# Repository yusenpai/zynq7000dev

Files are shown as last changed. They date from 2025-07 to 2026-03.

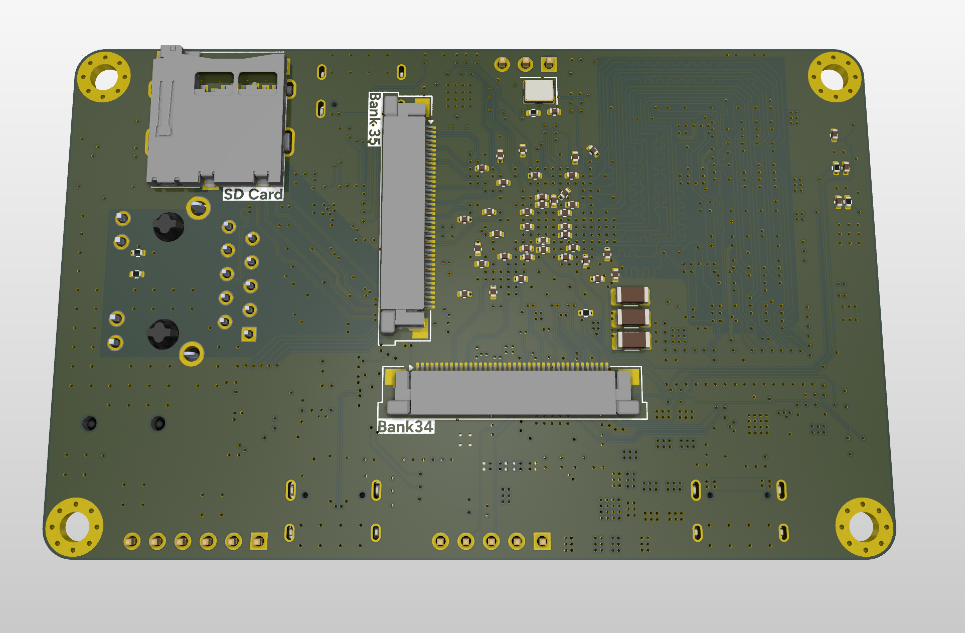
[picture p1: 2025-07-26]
demo/pcb/3d_bot.png

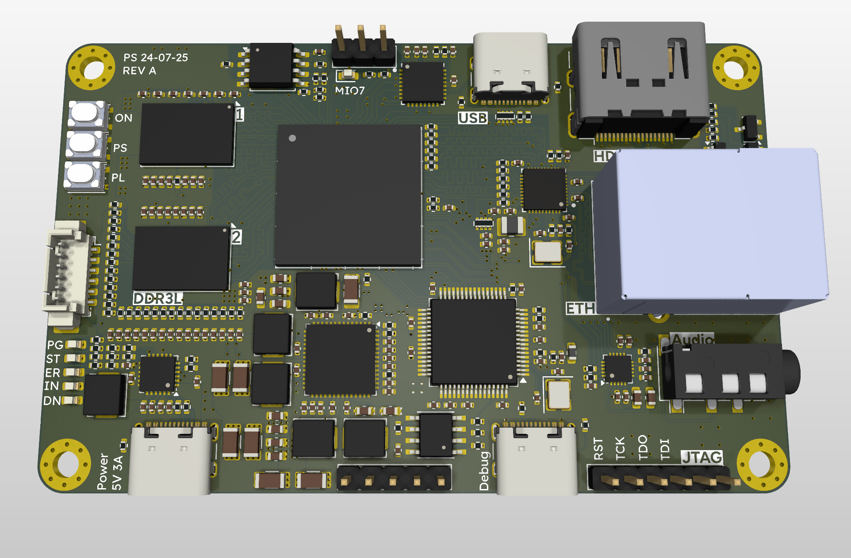
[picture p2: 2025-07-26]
demo/pcb/3d_top.png

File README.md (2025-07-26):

# Zynq 7000 SoC Dev Board

Đây là một board PCB 6 lớp thiết kế quanh con chip XC7Z010-1CLG400C, thuộc họ SoC Zynq 7000 của AMD. Con chip có một nửa là (2) lõi CPU (ARM Cortex-A9) + một đống ngoại vi (UART, I2C, SPI, USB,...); nửa còn lại là FPGA. Rất phù hợp cho những ứng dụng kết hợp Hardware + Software.

Thường thì những board FPGA (đặc biệt là thể loại SoC thế này) rất mắc tiền. Xem [https://www.amd.com/en/products/adaptive-socs-and-fpgas/evaluation-boards/ek-z7-zc702-g.html]. Trong khi đó, mạch in khá là rẻ, chip thì mình cũng kiếm được trên Aliexpress (với đi freesample), nên mình quyết định làm một board thế này.

Schematic, PCB vẫn đang trong quá trình phát triển và có thể sai sót. Mình sẽ cập nhật thêm nếu mạch chạy được 😂.

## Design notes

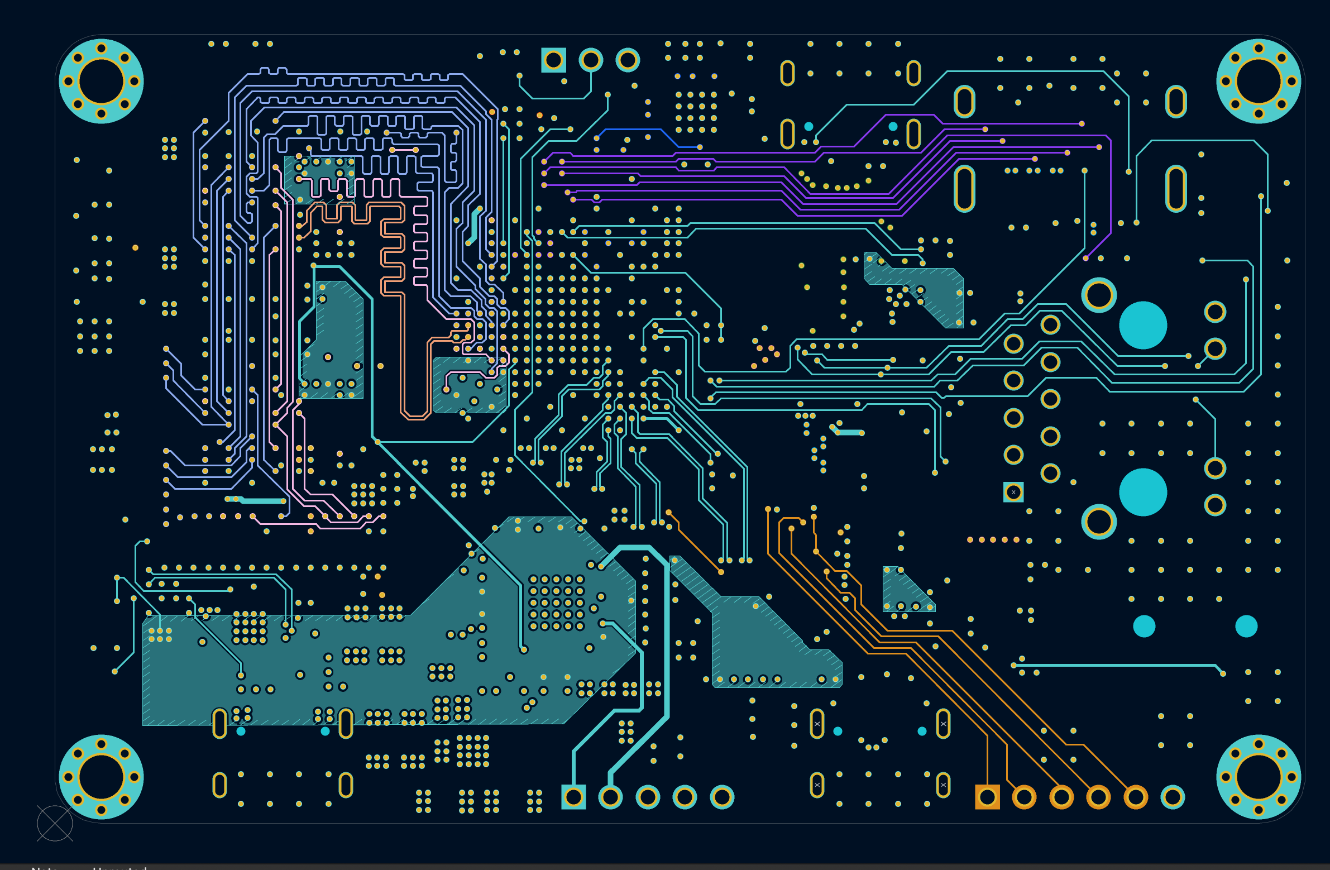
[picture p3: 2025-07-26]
demo/pcb/l3.png

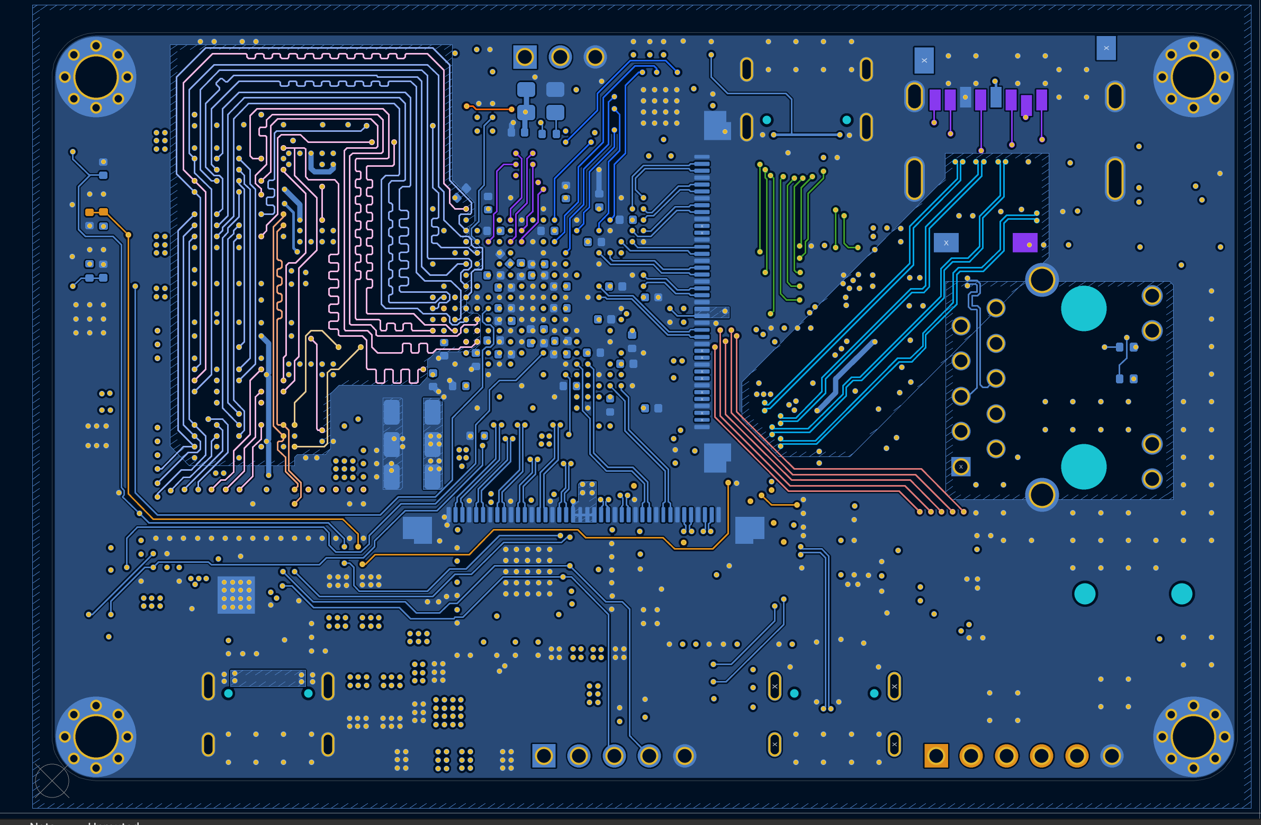
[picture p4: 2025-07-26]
demo/pcb/bot.png

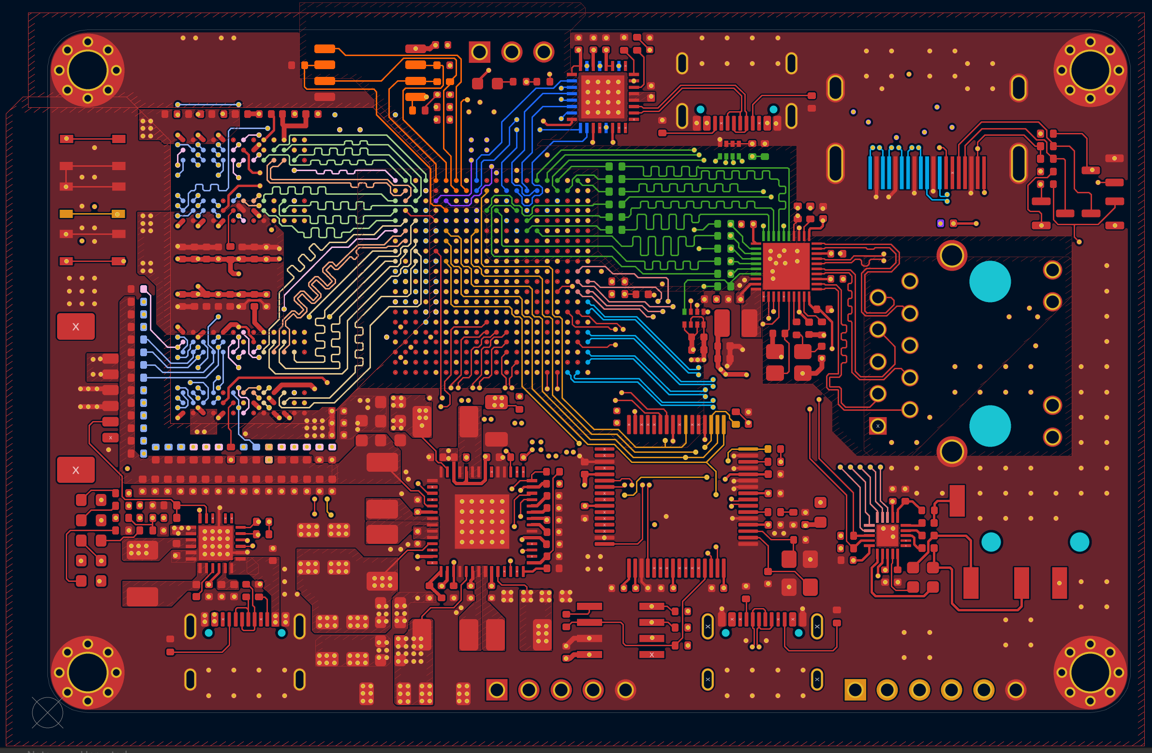
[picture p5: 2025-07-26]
demo/pcb/top.png

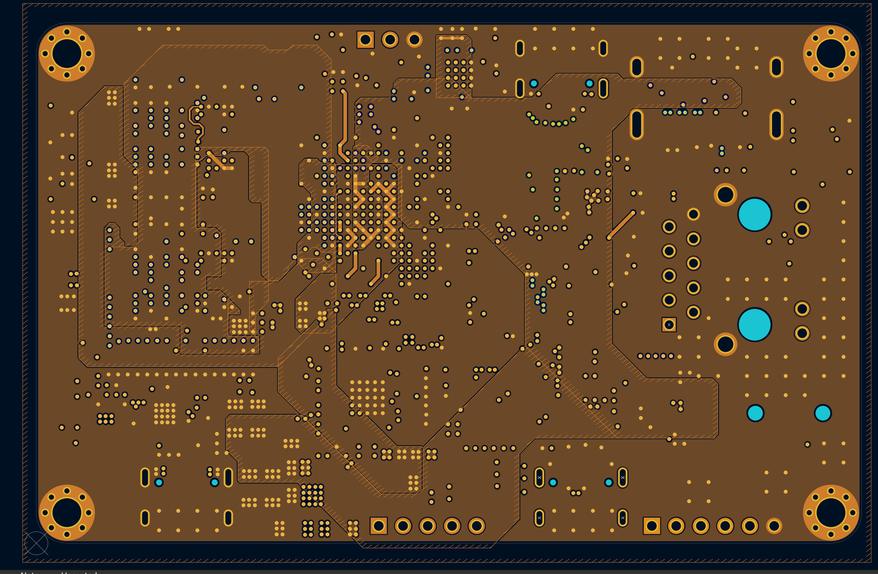
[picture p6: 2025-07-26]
demo/pcb/l2.png

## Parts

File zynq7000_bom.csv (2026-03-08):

Reference | Value | Footprint | Qty | DNP
C1,C2,C3,C4,C5,C6,C7,C8,C10,C11,C12,C13,C14,C15,C16,C17,C18,C19,C20,C21,C22,C23,C24,C25,C26,C81,C94,C95,C96,C99,C100,C103,C106,C109,C112,C115,C119,C120,C121,C122,C124,C126,C127,C128,C129,C133,C134,C135,C136,C143,C172 | 470n | Capacitor_SMD:C_0402_1005Metric | 51
C27,C28,C47 | 10n | Capacitor_SMD:C_0402_1005Metric | 3
C29,C30,C87,C89,C144,C145,C149 | 10u | Capacitor_SMD:C_0402_1005Metric | 7
C31,C32,C59,C60,C61,C62,C63,C64,C65,C88,C90,C91,C93,C98,C102,C105,C108,C111,C114,C117,C118,C125,C131,C132,C157,C168 | 4u7 | Capacitor_SMD:C_0402_1005Metric | 26
C33,C34,C35,C36,C37,C38,C39,C40,C41,C42,C43,C44,C45,C46,C48,C49,C50,C51,C54,C58,C72,C75,C80,C139,C140,C141,C142,C146,C147,C148,C150,C153,C154,C155,C156,C158,C159,C160,C161,C162,C163,C164,C165,C166,C167,C169 | 100n | Capacitor_SMD:C_0402_1005Metric | 46
C52,C53,C55,C76,C79,C82,C84,C85,C152,C175,L1,L2,L3,L4,L5,L6 | 1u | Capacitor_SMD:C_0402_1005Metric,Inductor_SMD:L_Chilisin_BMRA00040420 | 16
C56,C57,C66,C67,C68,C69,C70,C71,C73,C74,C77,C78 | 22u | Capacitor_SMD:C_0603_1608Metric | 12
C83 | 220n | Capacitor_SMD:C_0402_1005Metric | 1
C86 | 47n | Capacitor_SMD:C_0402_1005Metric | 1
C92,C97,C107,C110,C113 | 100u | Capacitor_SMD:C_1206_3216Metric | 5
C101,C104,C116,C123,C130 | 47u | Capacitor_SMD:C_1206_3216Metric | 5
C137,C138,C170,C171 | 10p | Capacitor_SMD:C_0402_1005Metric | 4
C151,C174,L7 | 2u2 | Capacitor_SMD:C_0402_1005Metric,Inductor_SMD:L_1008_2520Metric | 3
D1,D4 | RED | LED_SMD:LED_0603_1608Metric | 2
D2 | GREEN | LED_SMD:LED_0603_1608Metric | 1
D3 | BLUE | LED_SMD:LED_0603_1608Metric | 1
D5 | STAT | LED_SMD:LED_0603_1608Metric | 1
D6 | PG | LED_SMD:LED_0603_1608Metric | 1
FB1 | 600R | Inductor_SMD:L_0603_1608Metric | 1
IC1 | MMPF0100NPAEP | Package_DFN_QFN:QFN-56-1EP_8x8mm_P0.5mm_EP4.3x4.3mm | 1
J1,J2 | FPC 40 pins P0.5mm | Connector_FFC-FPC:Amphenol_F32Q-1A7x1-11040_1x40-1MP_P0.5mm_Horizontal | 2
J3,J5,J13 | Header 2.54mm | Connector_PinHeader_2.54mm:PinHeader_1x03_P2.54mm_Vertical,Connector_PinHeader_2.54mm:PinHeader_1x05_P2.54mm_Vertical,Connector_PinHeader_2.54mm:PinHeader_1x06_P2.54mm_Vertical | 3
J4 | AudioJack4 | Connector_Audio:Jack_3.5mm_PJ320D_Horizontal | 1
J6,J9,J11 | USB_C_Receptacle_USB2.0_16P | Connector_USB:USB_C_Receptacle_GCT_USB4105-xx-A_16P_TopMnt_Horizontal | 3
J7 | MX_1.25mm | Connector_Molex:Molex_PicoBlade_53398-0671_1x06-1MP_P1.25mm_Vertical | 1
J8 | HR911130A | Custom:HANRUN_HR911130A | 1
J10 | Micro_SD_Card_Det1 | Custom:5008730806 | 1
J12 | HDMI_A_1.4 | Connector_Video:HDMI_A_Molex_208658-1001_Horizontal | 1
Q1,Q2,Q3 | 2N7002 | Package_TO_SOT_SMD:SOT-23 | 3
R1,R39,R41,R52,R68,R76,R77,R79,R81,R82,R91 | 1k | Resistor_SMD:R_0402_1005Metric | 11
R2,R5,R19 | 120R | Resistor_SMD:R_0402_1005Metric | 3
R3,R4 | 240R | Resistor_SMD:R_0402_1005Metric | 2
R6,R7,R8,R35,R38,R40,R43,R50,R51,R54,R55,R56,R57,R75,R96,R97,R98,R99,R100 | 4k7 | Resistor_SMD:R_0402_1005Metric | 19
R9,R10,R11,R12,R13,R14,R15,R16,R17,R18,R20,R21,R22,R23,R24,R25,R26,R27,R28,R29,R30,R31,R32,R33 | 60R4 | Resistor_SMD:R_0402_1005Metric | 24
R34,R36,R37,R86,R90,R92,R93,R94 | 10k | Resistor_SMD:R_0402_1005Metric | 8
R42 | 330R | Resistor_SMD:R_0402_1005Metric | 1
R44,R45,R46,R47,R48,R49,R69,R70,R71,R72,R73,R74,R80,R108 | 22R | Resistor_SMD:R_0402_1005Metric | 14
R53,R64,R65 | 2k2 | Resistor_SMD:R_0402_1005Metric | 3
R58 | 100k | Resistor_SMD:R_0402_1005Metric | 1
R59 | DNP | Resistor_SMD:R_0402_1005Metric | 1
R60 | DNP | Resistor_SMD:R_0402_1005Metric | 1 | DNP
R61,R62,R66,R83,R84,R87,R88 | 5k1 | Resistor_SMD:R_0402_1005Metric | 7
R63 | 0R | Resistor_SMD:R_0402_1005Metric | 1 | DNP
R67 | 30k | Resistor_SMD:R_0402_1005Metric | 1
R78 | 2k49 | Resistor_SMD:R_0402_1005Metric | 1
R85 | 6k8 | Resistor_SMD:R_0402_1005Metric | 1
R89,R95 | 2k | Resistor_SMD:R_0402_1005Metric | 2
R101,R102,R103,R104,R105,R106,R107 | 20k | Resistor_SMD:R_0402_1005Metric | 7
R109 | 1k2 | Resistor_SMD:R_0402_1005Metric | 1
RN1,RN2 | 3k | Resistor_SMD:R_Array_Concave_4x0402 | 2
SW1,SW2,SW3 | SW_Push | Button_Switch_SMD:SW_Push_1P1T_NO_Vertical_Wuerth_434133025816 | 3
U1 | XC7Z010-1CLG400C | Custom:CLG400_XIL-L | 1
U2,U3 | H5TC2G83EFR-xxA | Package_BGA:FBGA-78_7.5x11mm_Layout2x3x13_P0.8mm | 2
U4 | SGTL5000XNLA3 | Package_DFN_QFN:QFN-20-1EP_3x3mm_P0.4mm_EP1.65x1.65mm | 1
U5 | BQ25601 | Package_DFN_QFN:Texas_RTW_WQFN-24-1EP_4x4mm_P0.5mm_EP2.7x2.7mm_ThermalVias | 1
U6 | RTL8211F-CG | Custom:RTL8211F-CG_RTK | 1
U7 | USB3320C-EZK-TR | Custom:QFN32_5X5MC_MCH | 1
U8 | W25Q128JVS | Package_SO:SOIC-8_5.3x5.3mm_P1.27mm | 1
U9 | FT4232H | Package_QFP:LQFP-64_10x10mm_P0.5mm | 1
U10 | AT93C46-10SU-2.7-T | Custom:SOIC8_4P9X3P9MC_MCH | 1
X1 | ASE-40MHz | Oscillator:Oscillator_SMD_Abracon_ASE-4Pin_3.2x2.5mm | 1
Y1 | 25MHz | Crystal:Crystal_SMD_3225-4Pin_3.2x2.5mm | 1
Y2 | 12MHz | Crystal:Crystal_SMD_3225-4Pin_3.2x2.5mm | 1

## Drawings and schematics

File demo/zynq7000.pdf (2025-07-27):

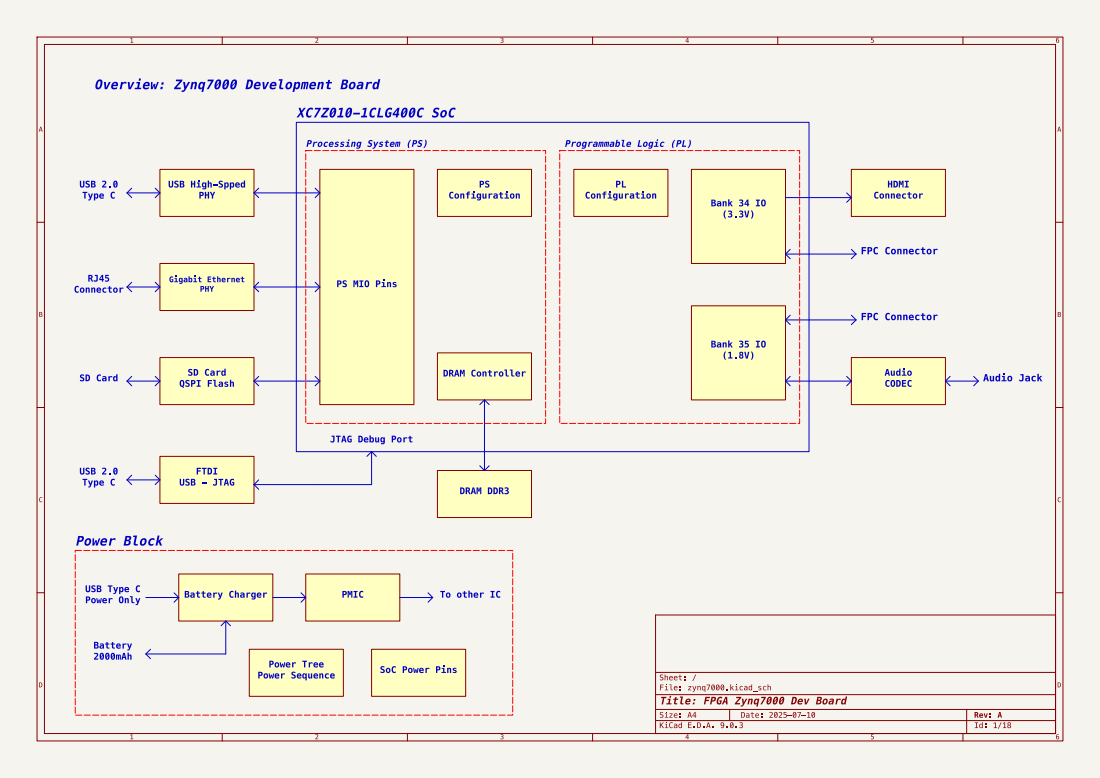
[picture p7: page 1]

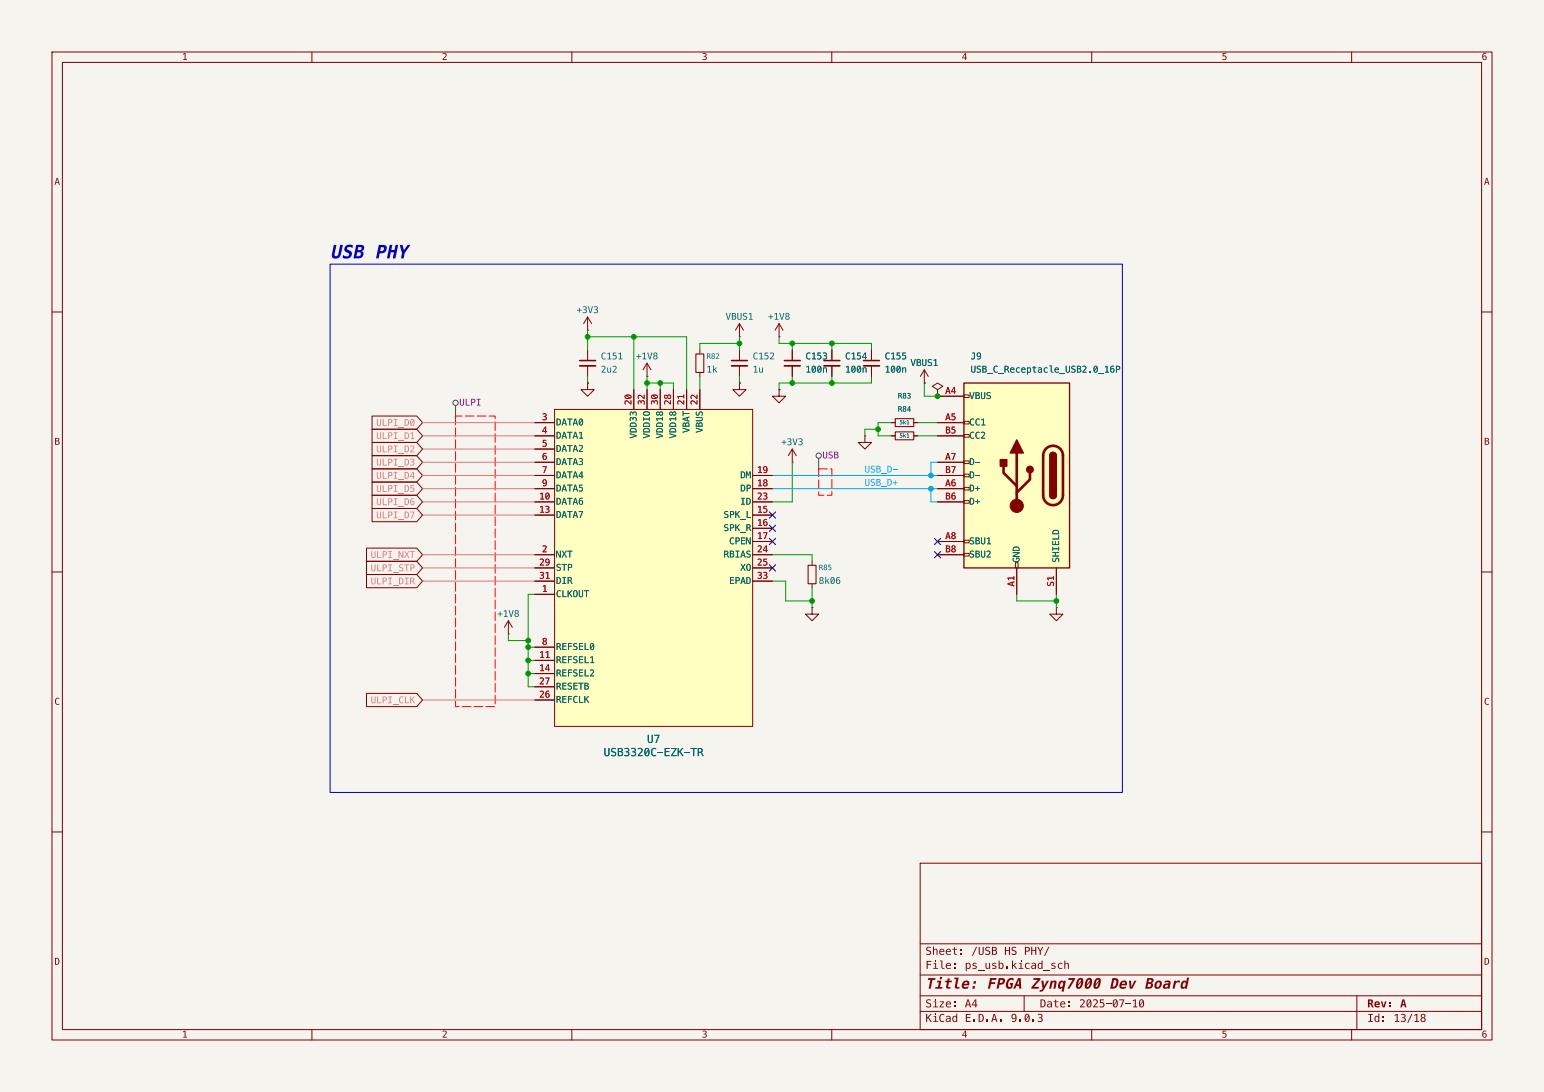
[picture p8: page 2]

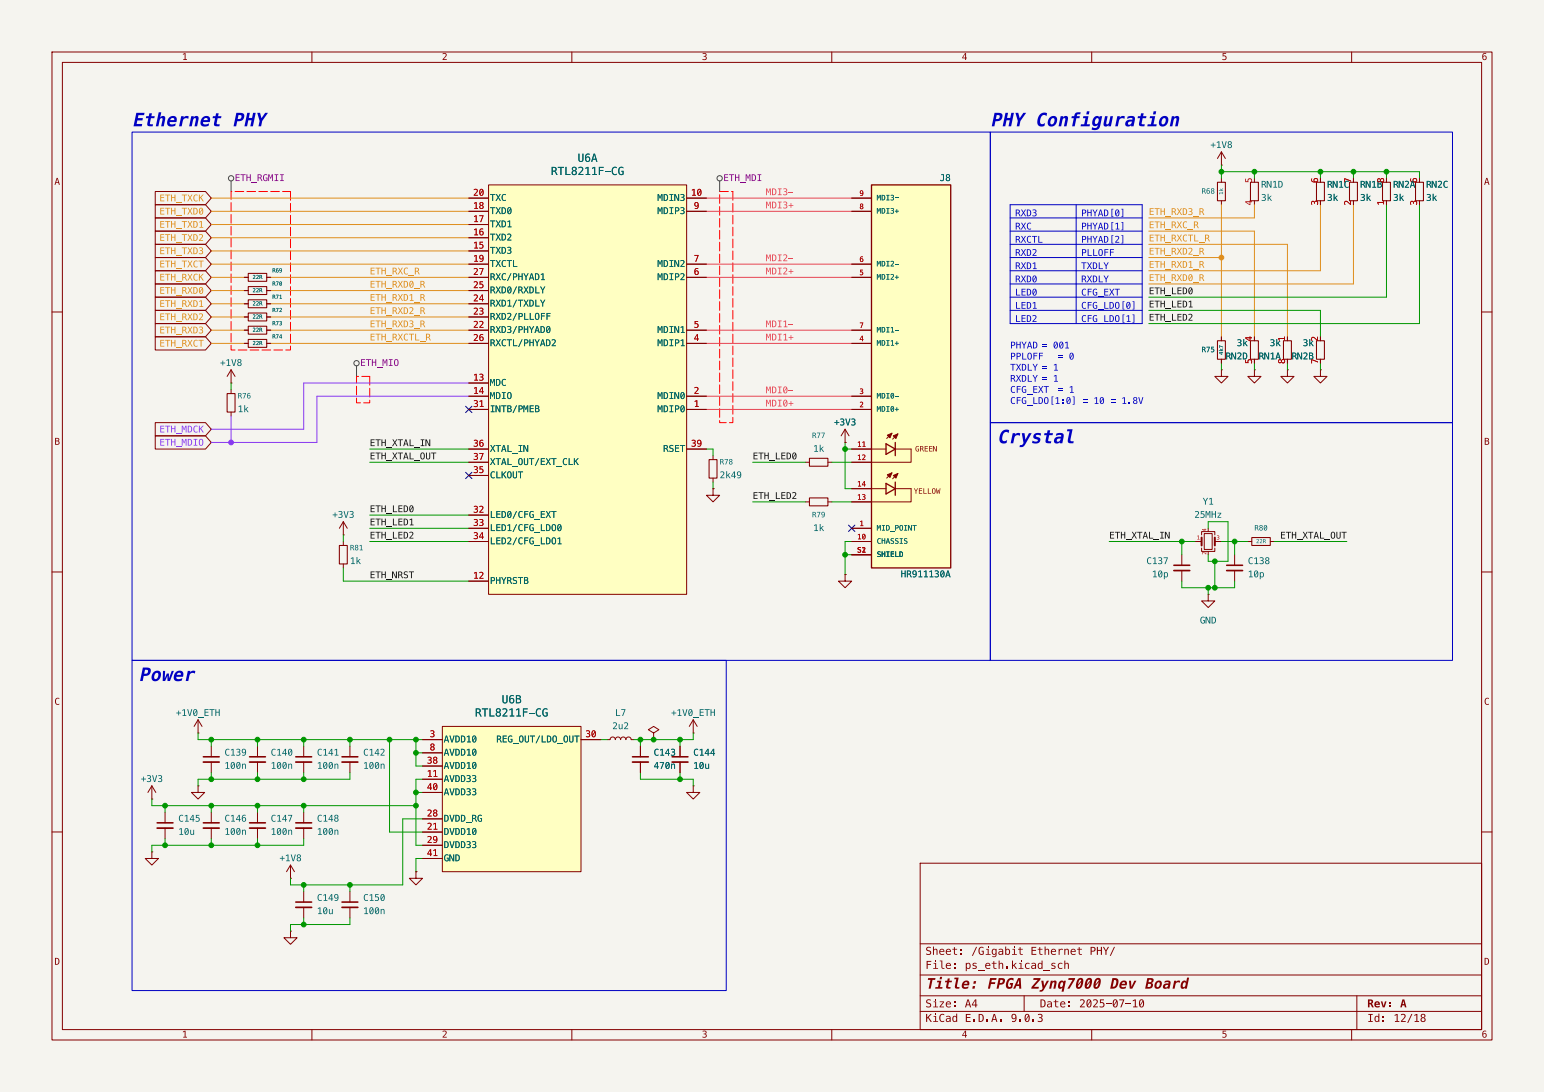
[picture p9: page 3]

22R | ETH_RXCTL_R | 5 MDIP1

2 MDIP0

Crystal

Power

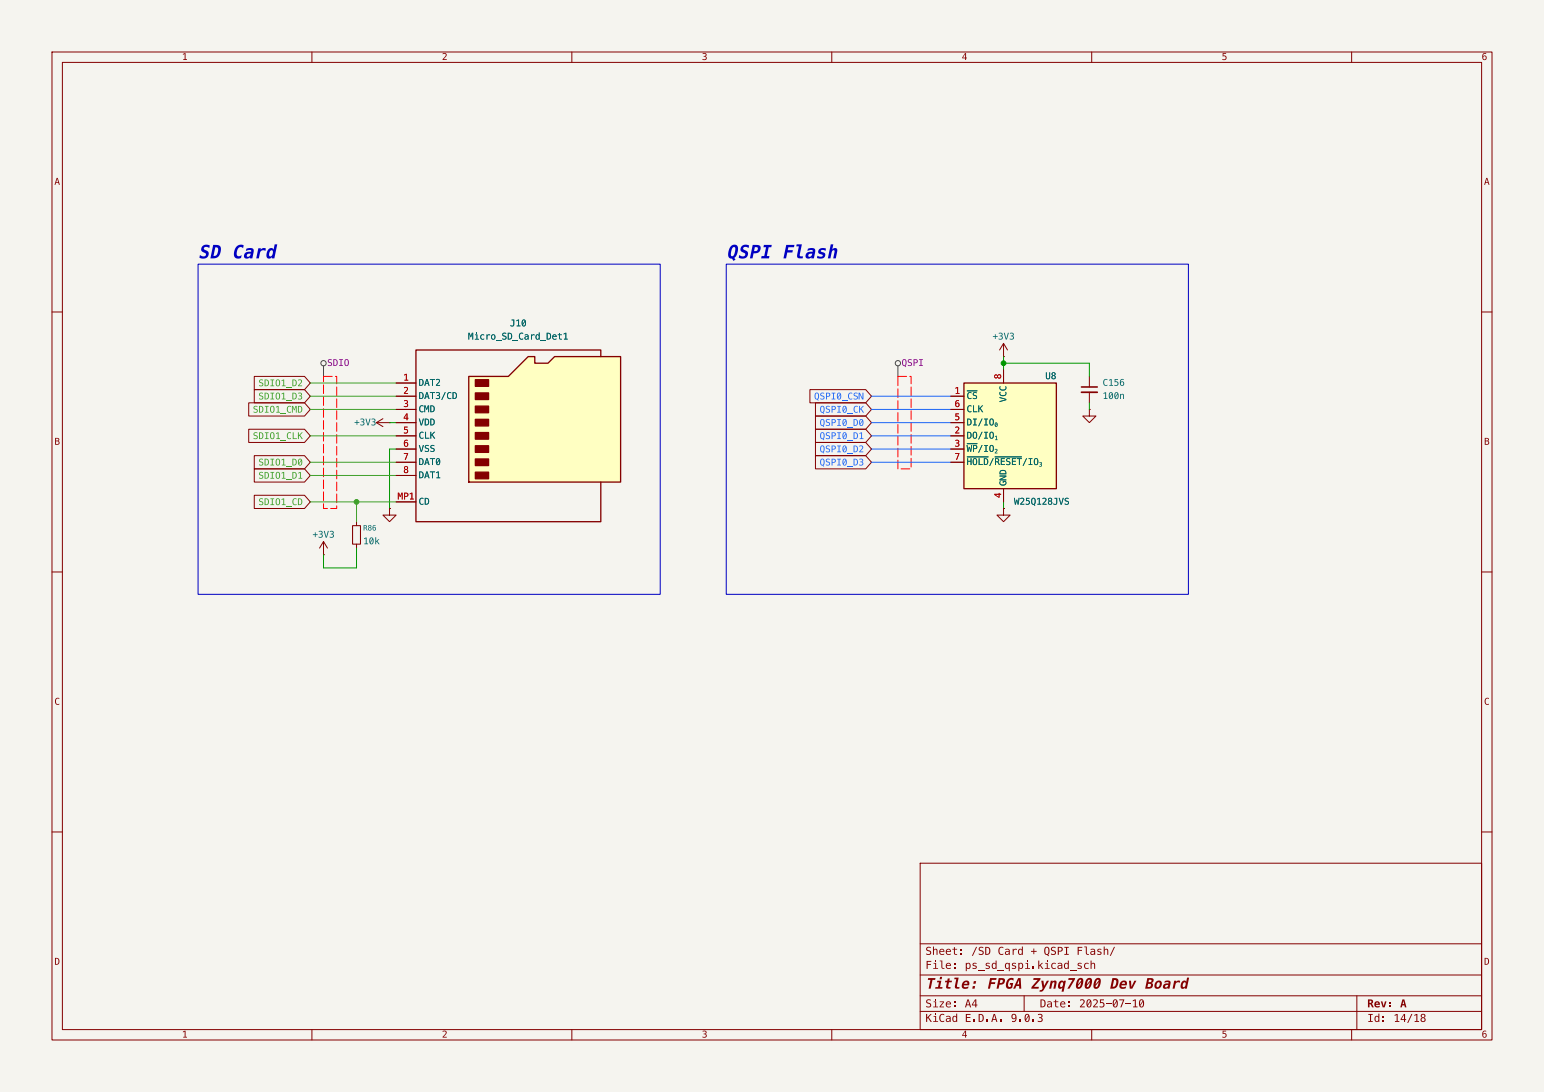
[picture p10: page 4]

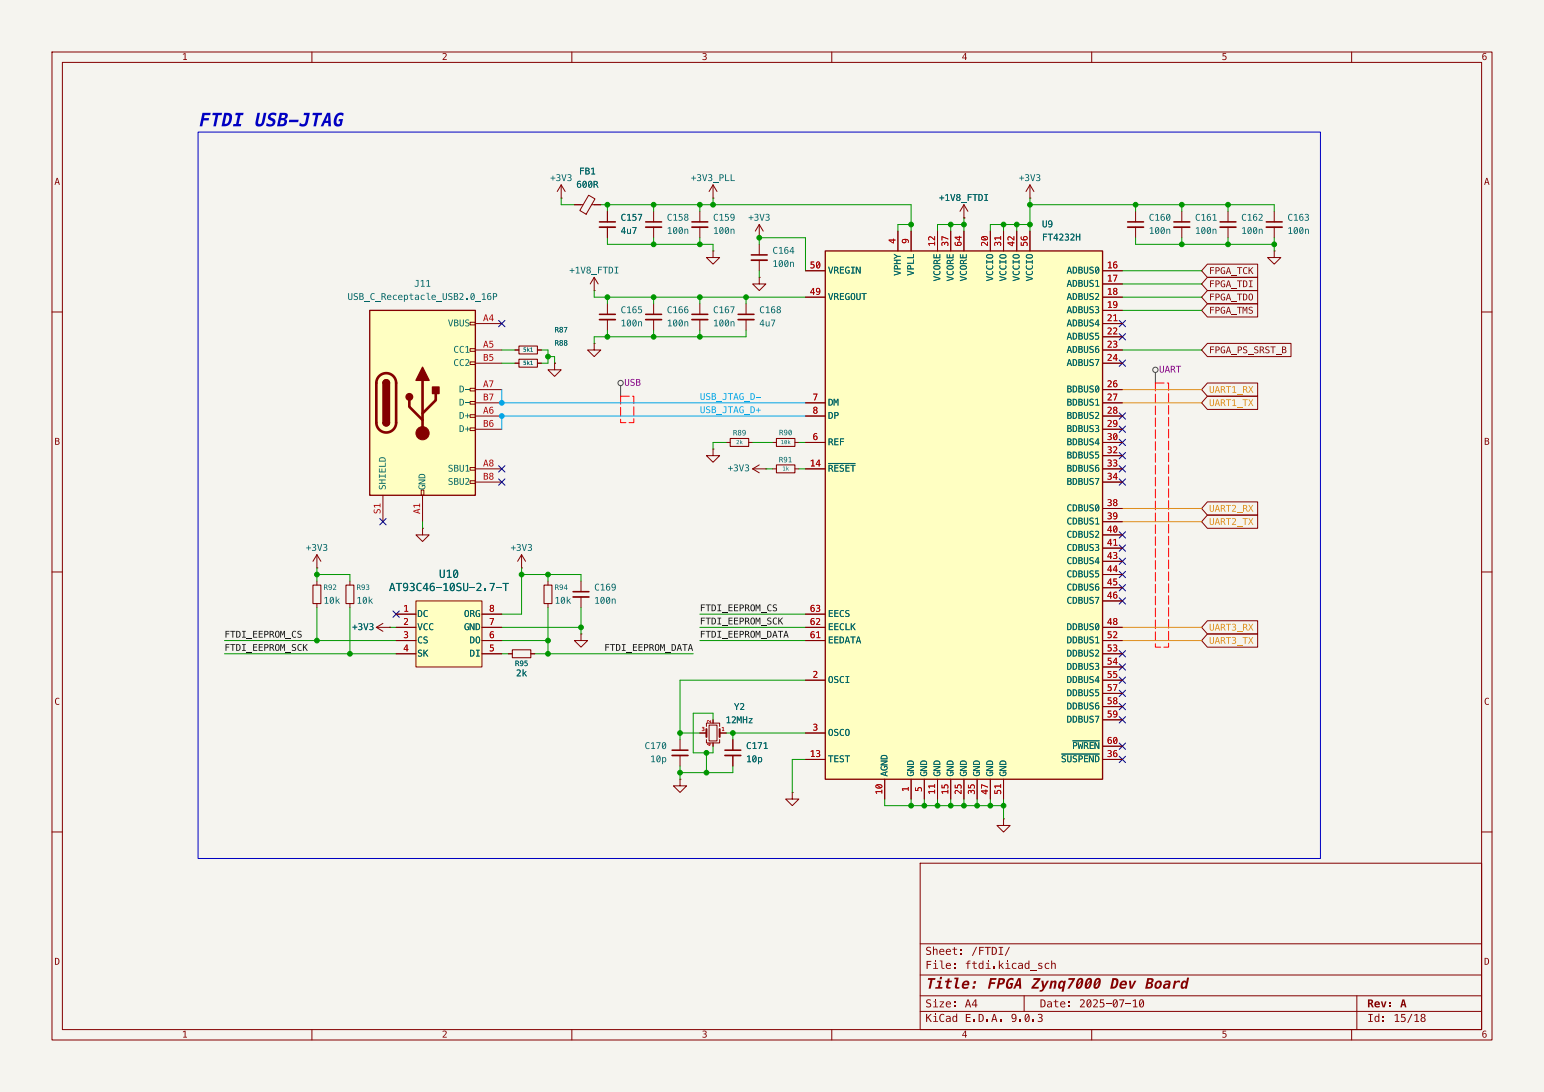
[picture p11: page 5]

5 VCORE 12 GND 11 VCORE 37 GND 15 VCORE 64 GND 25 GND 35 VCCIO 20 GND 47 VCCIO 31 GND 51 VCCIO 42 VCCIO 56 ADBUS0 16 ADBUS1 17 ADBUS2 18 ADBUS3 19 ADBUS4 21 ADBUS5 22 ADBUS6 23 ADBUS7 24 BDBUS0 26 BDBUS1 27 BDBUS2 28 BDBUS3 29 BDBUS4 30 BDBUS5 32 BDBUS6 33 BDBUS7 34 CDBUS0 38 CDBUS1 39 CDBUS2 40 CDBUS3 41 CDBUS4 43 CDBUS5 44 CDBUS6 45 CDBUS7 46 DDBUS0 48 DDBUS1 52 DDBUS2 53 DDBUS3 54 DDBUS4 55 DDBUS5 57 DDBUS6 58 DDBUS7 59 ~{PWREN} 60 ~{SUSPEND} 36

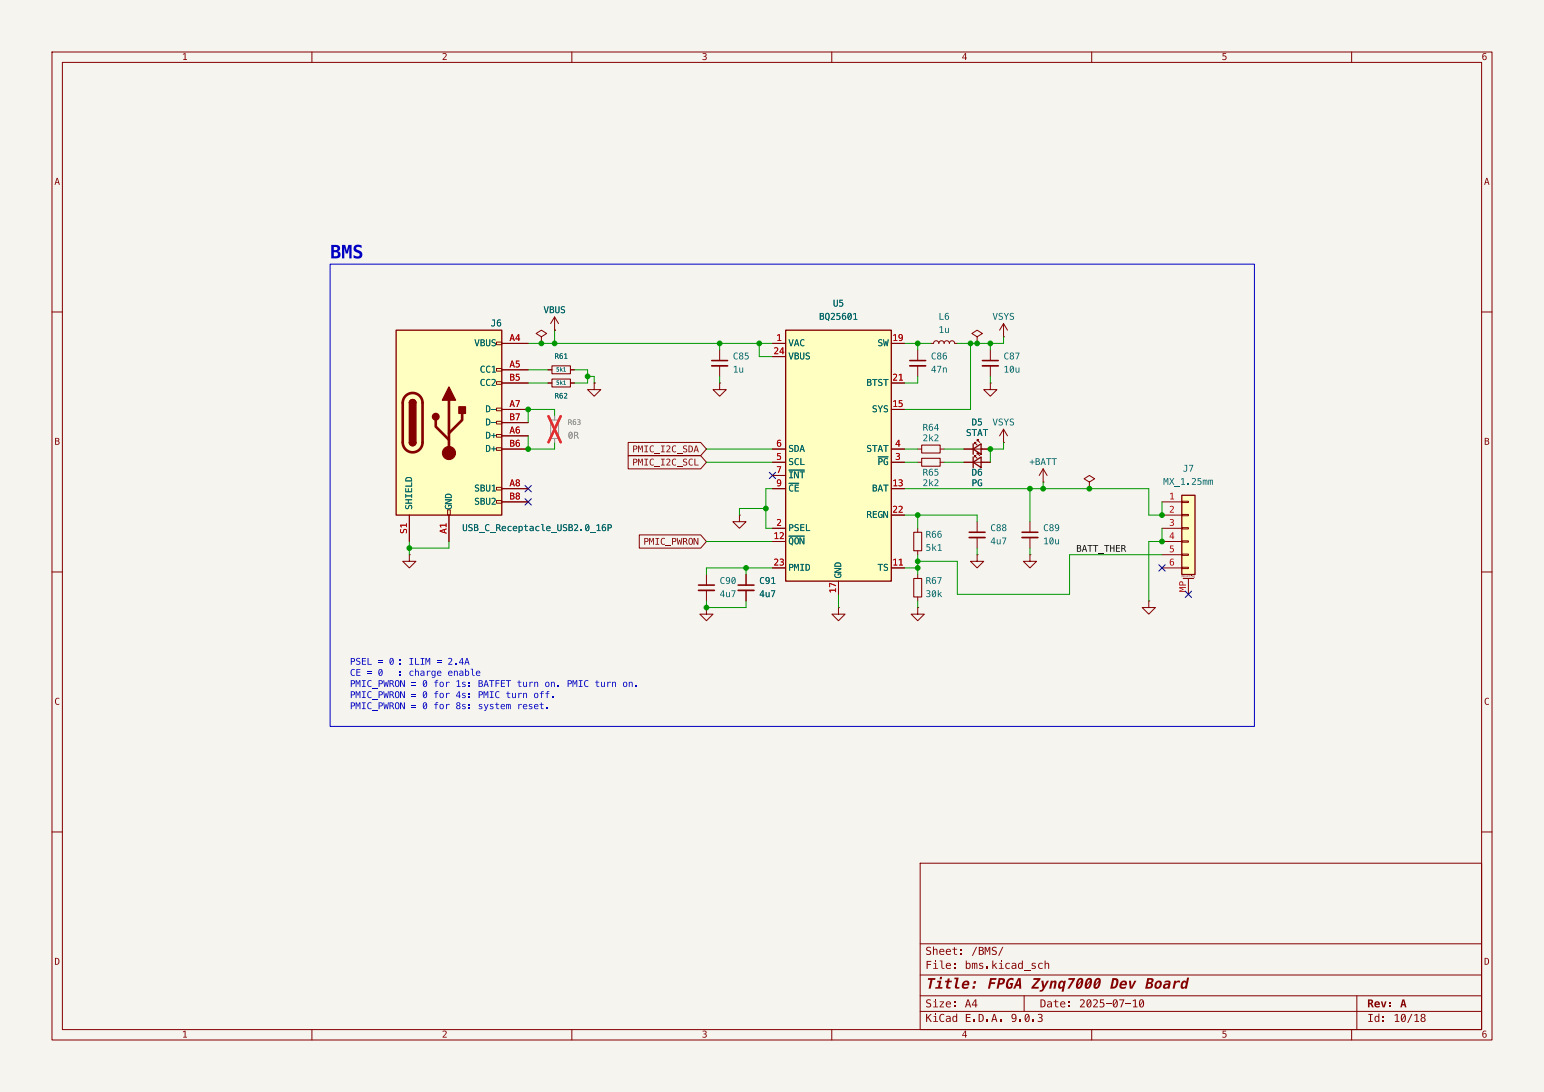
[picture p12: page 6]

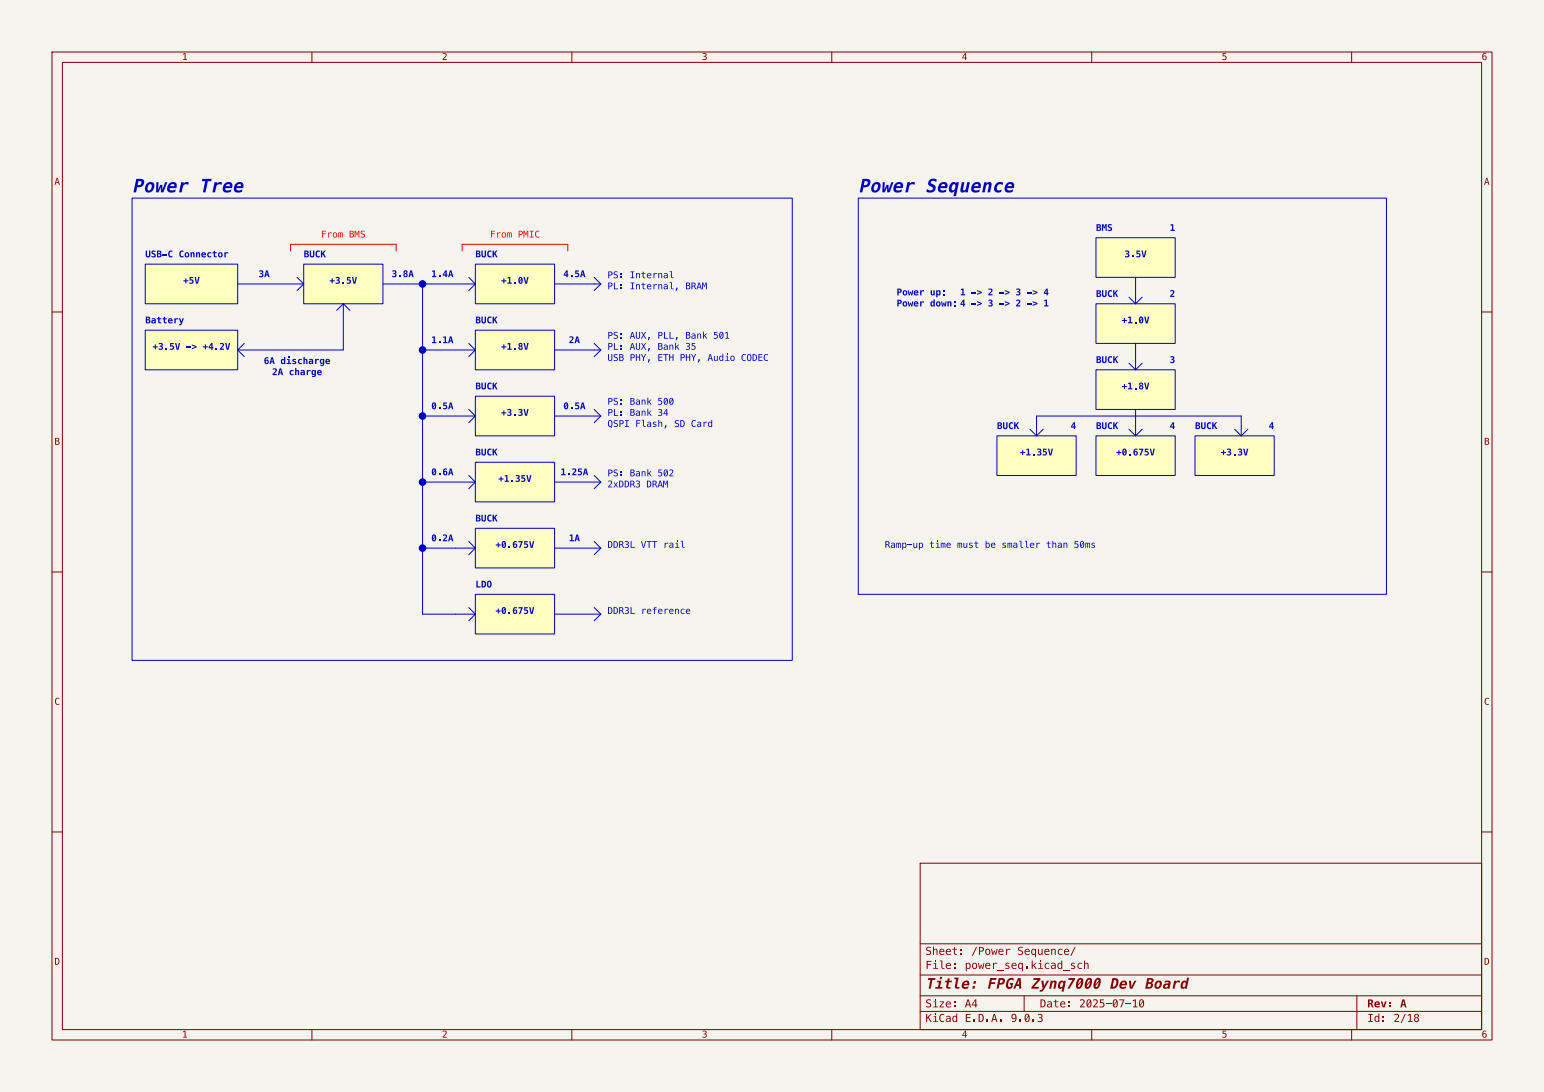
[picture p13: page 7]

USB-C Connector Power Tree

PS: AUX, PLL, Bank 501 PL: AUX, Bank 35 USB PHY, ETH PHY, Audio CODEC

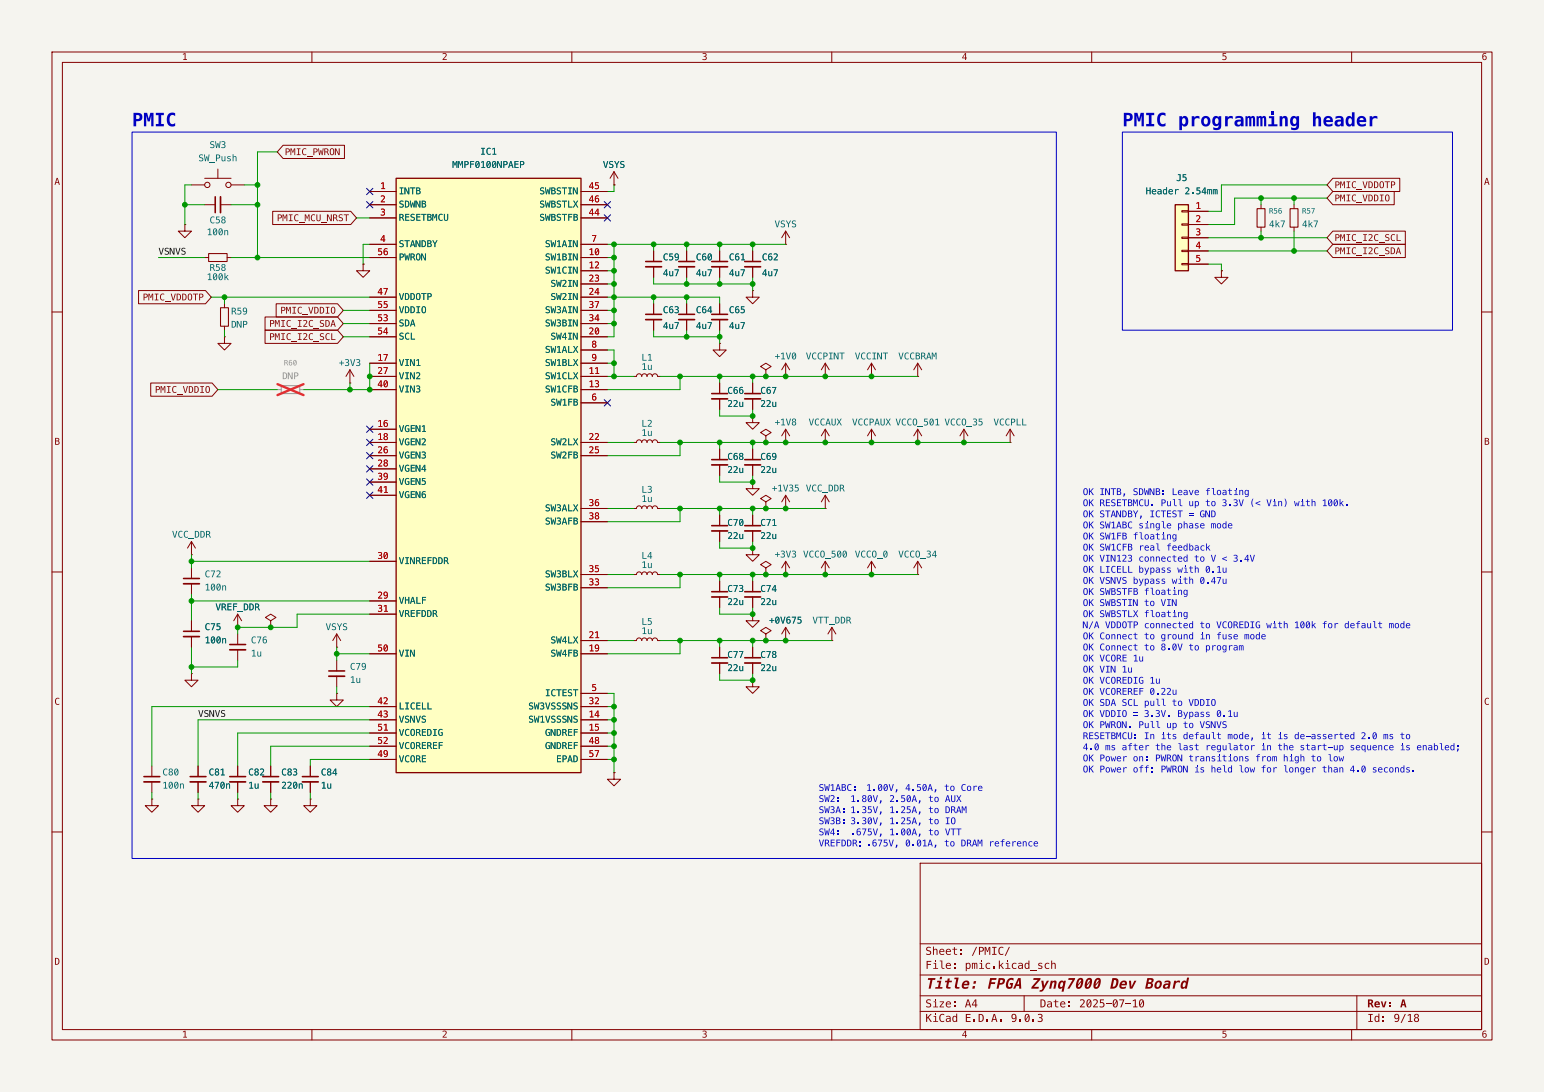
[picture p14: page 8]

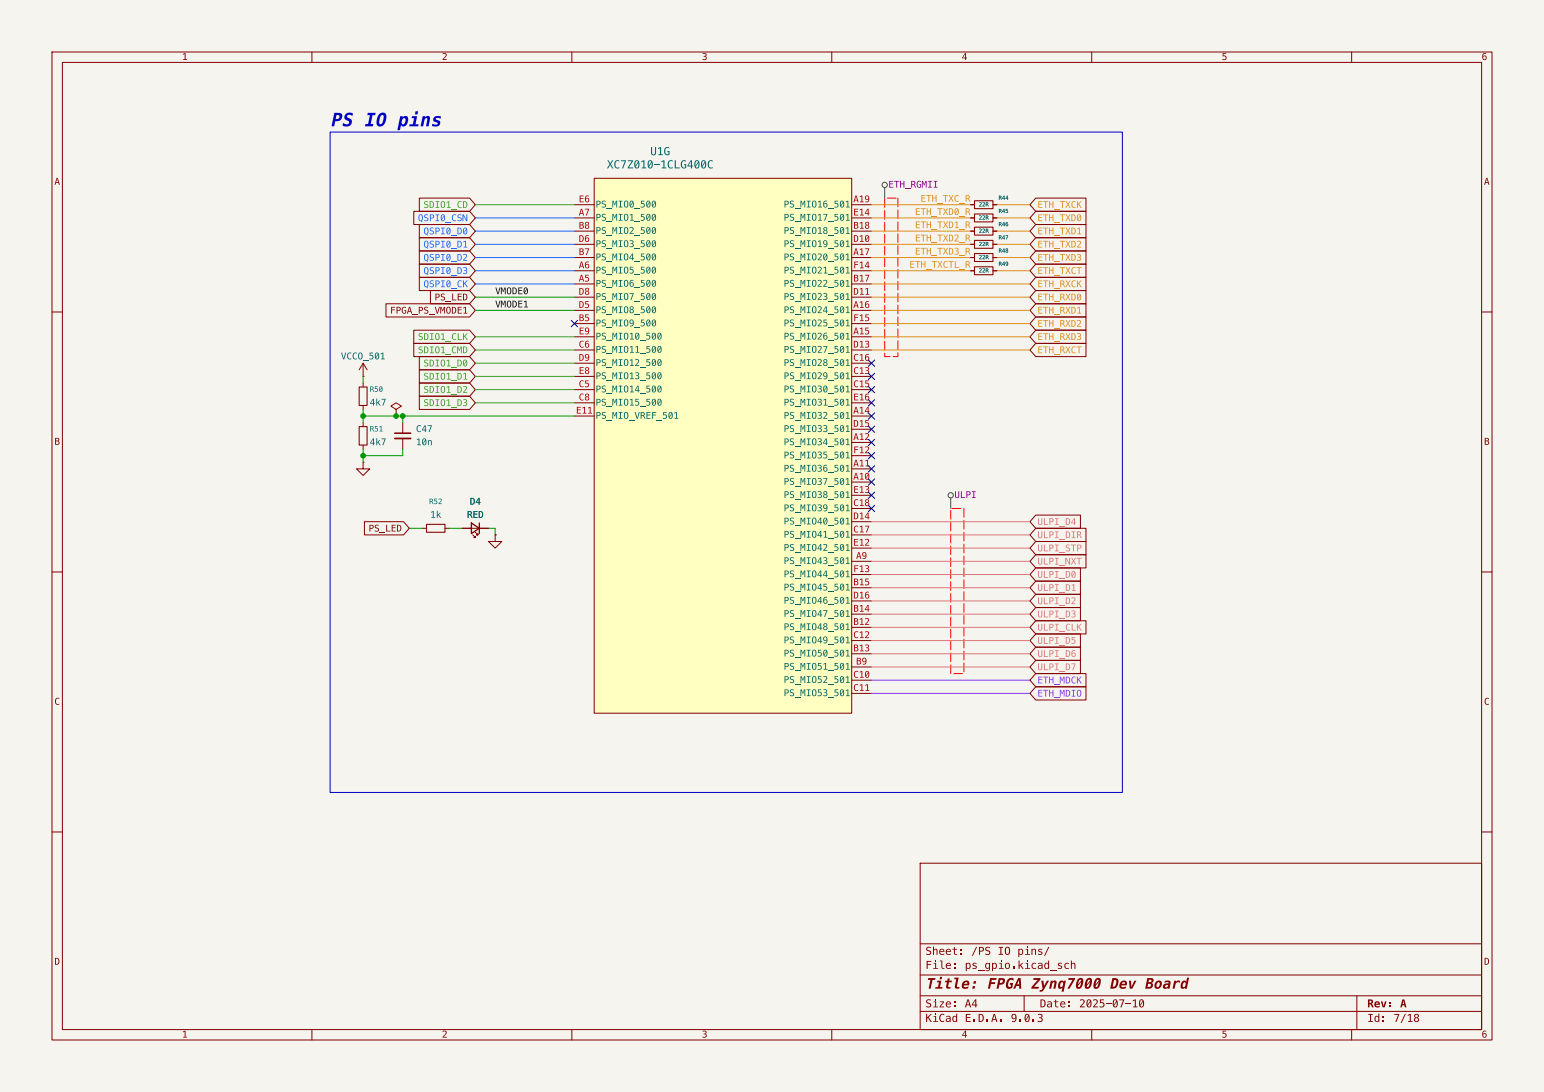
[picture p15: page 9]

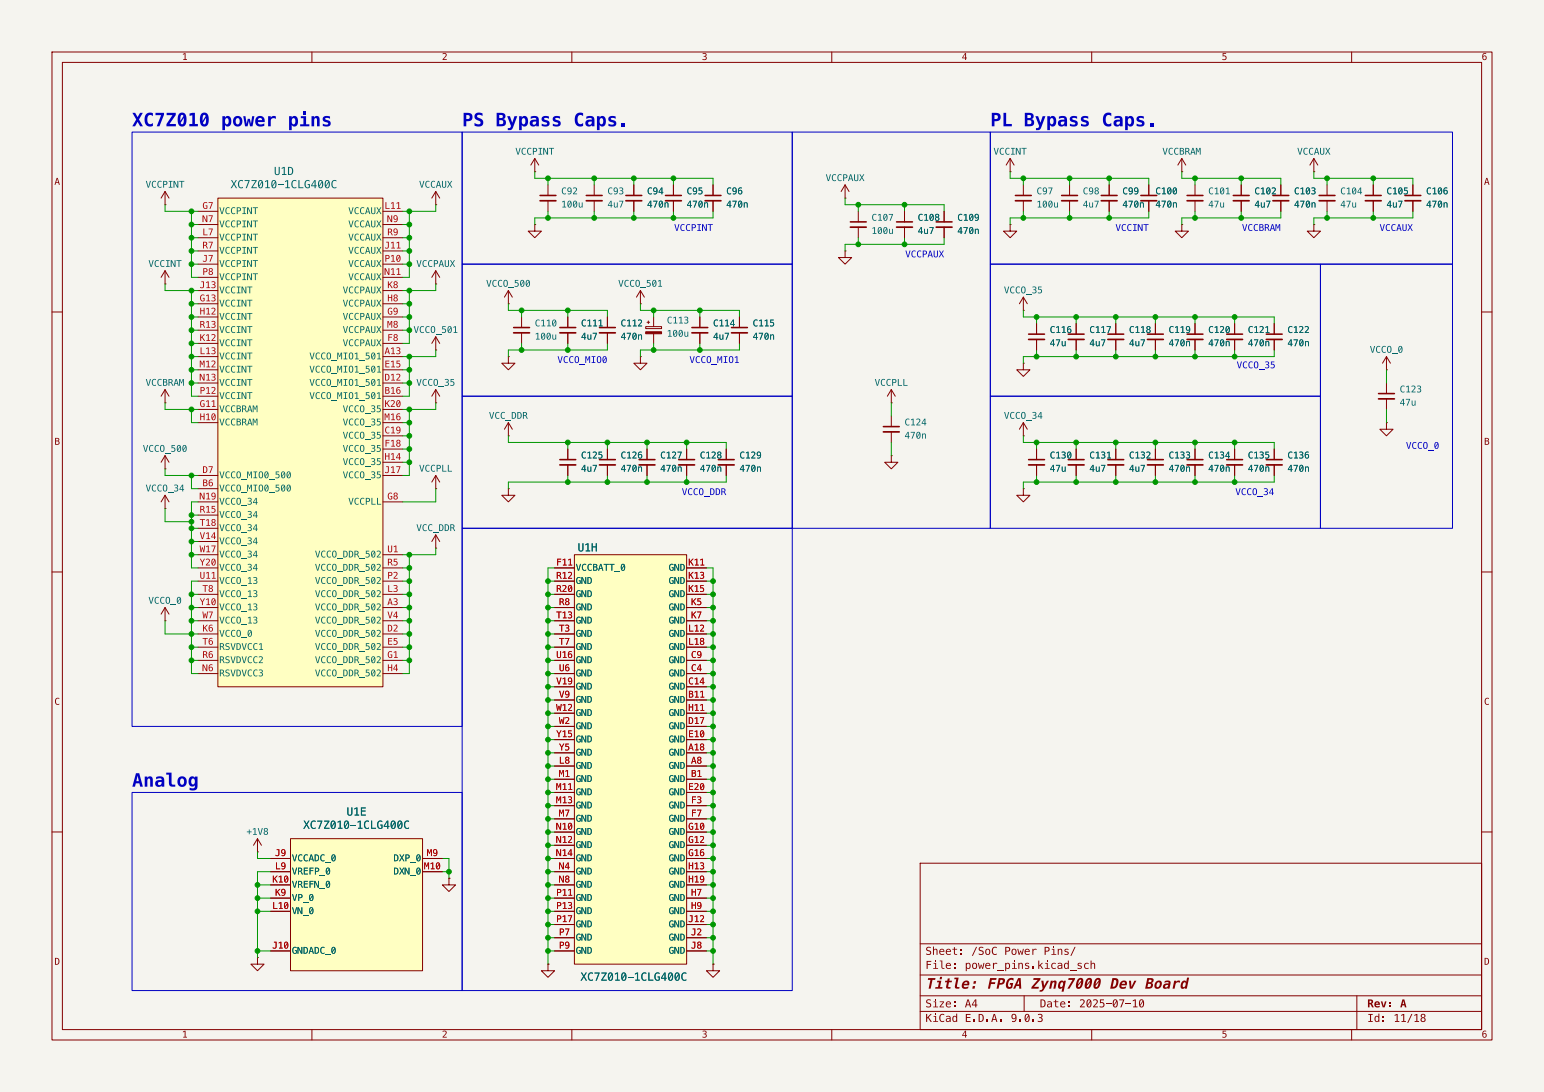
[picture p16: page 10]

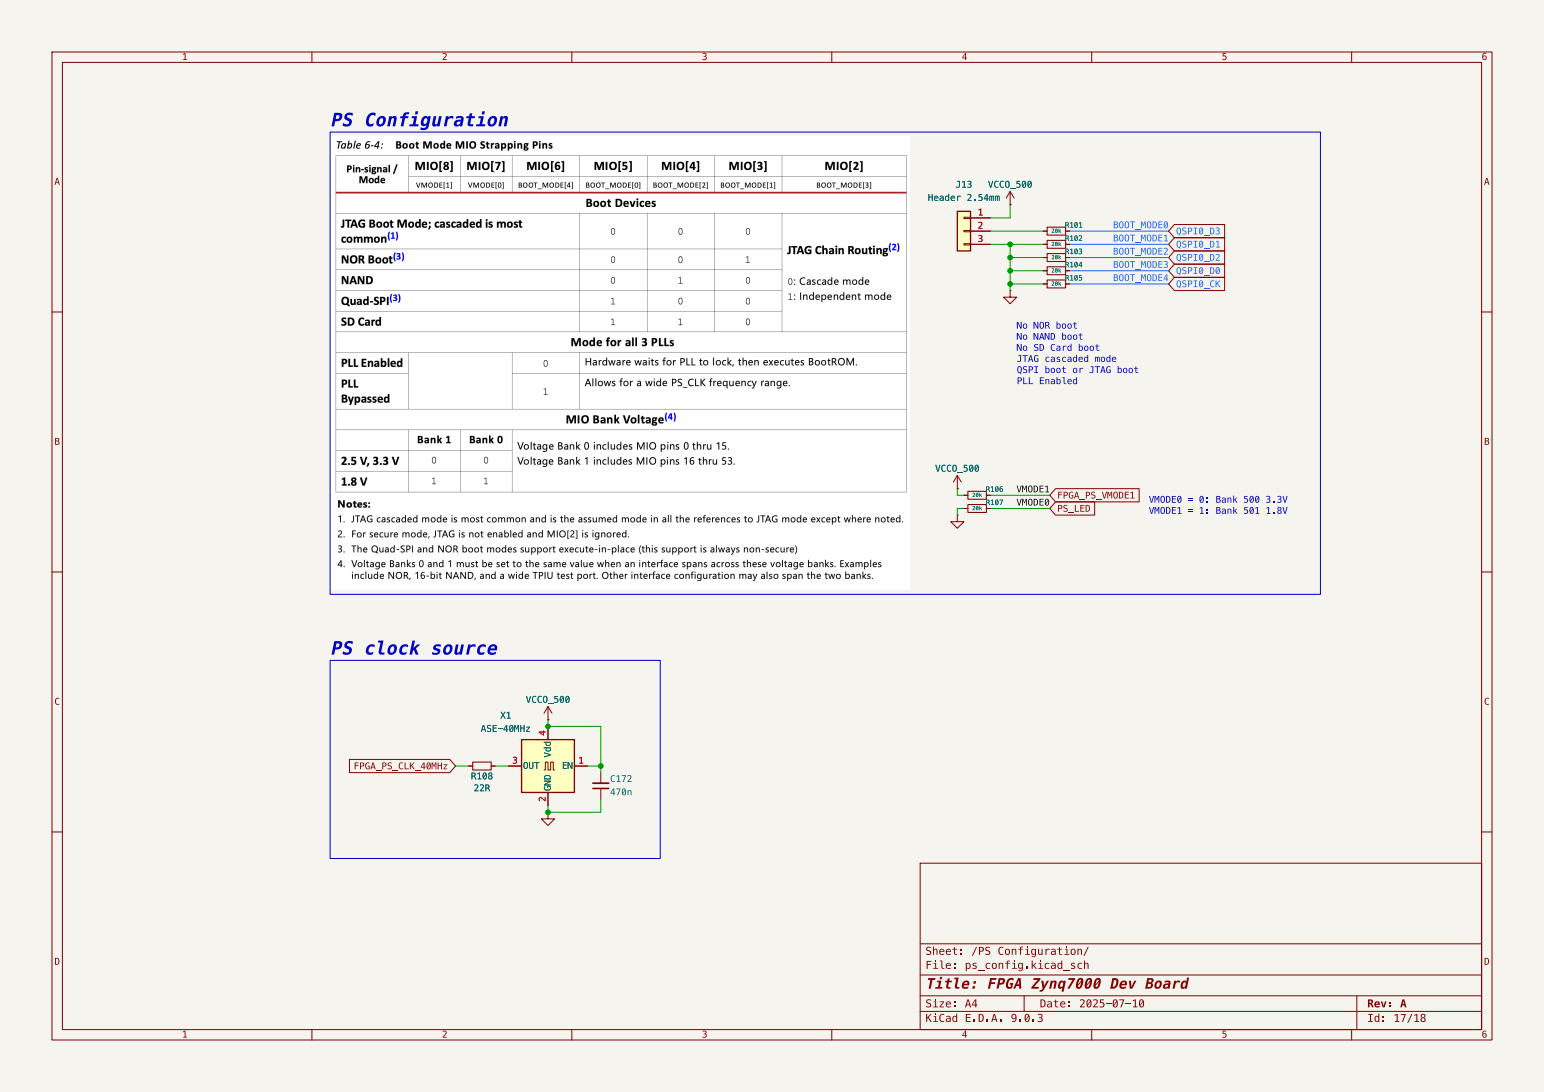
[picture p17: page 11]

J13 Header 2.54mm
No NOR boot No NAND boot No SD Card boot JTAG cascaded mode QSPI boot or JTAG boot PLL EnabledR103

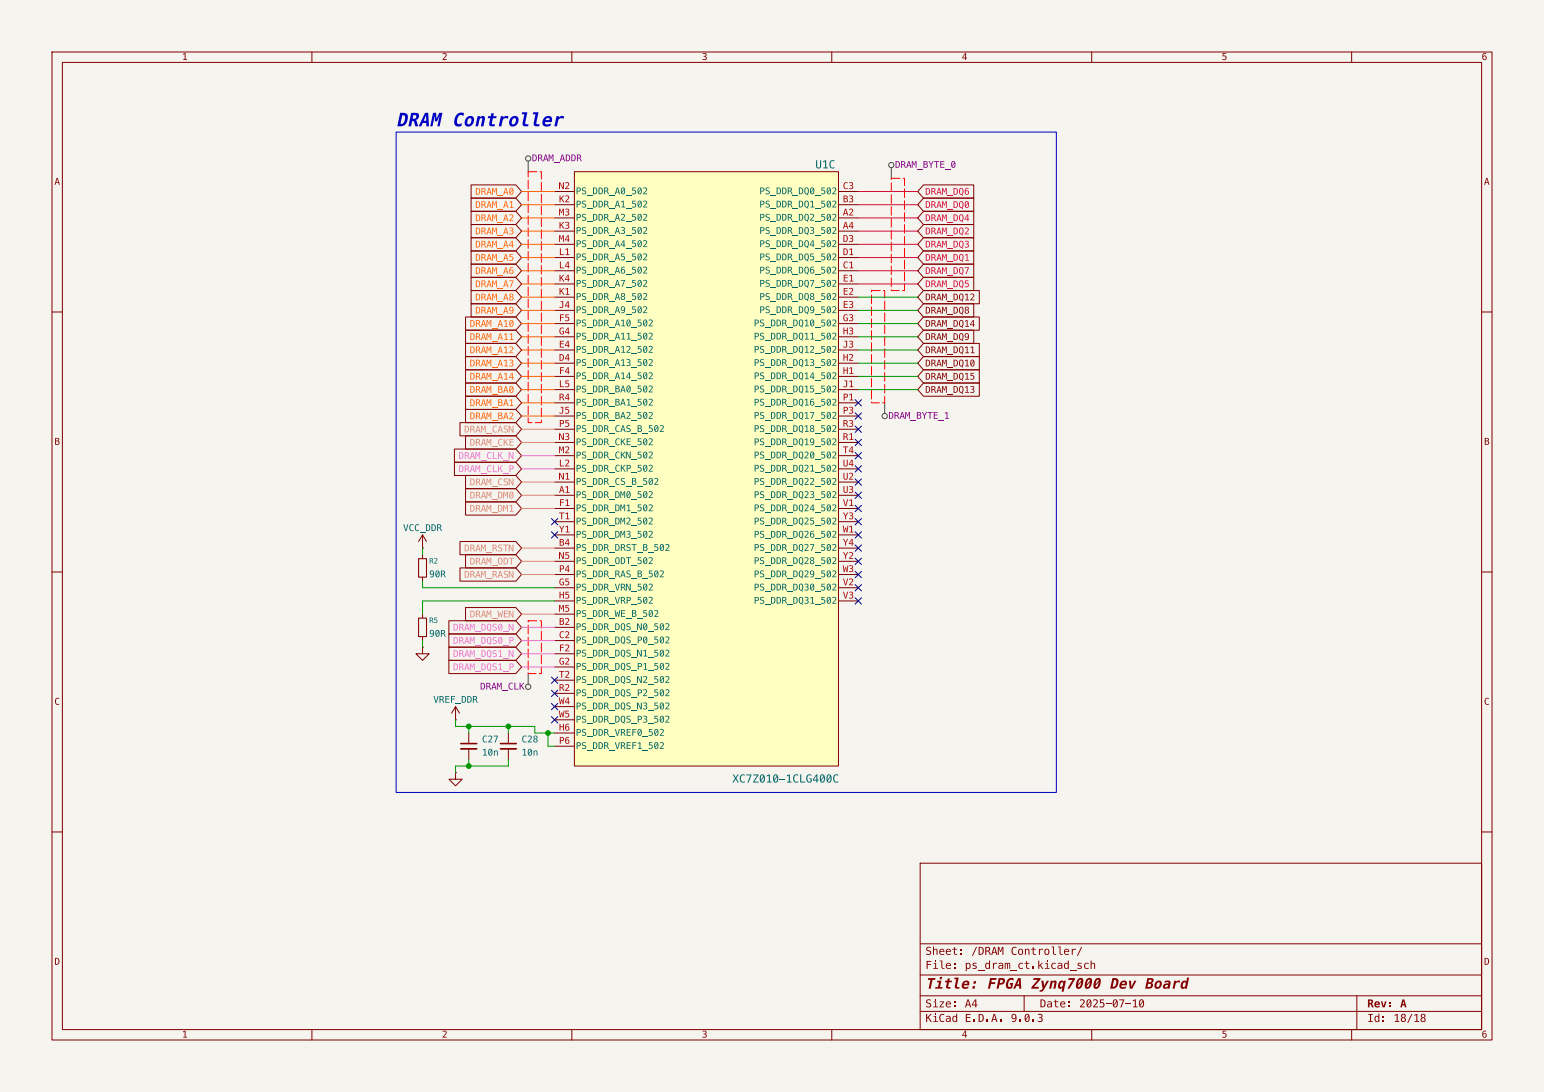
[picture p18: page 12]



3 3 FPGA_TDO
4 4
5 5




8 CKS 11 GND 17 SH SH


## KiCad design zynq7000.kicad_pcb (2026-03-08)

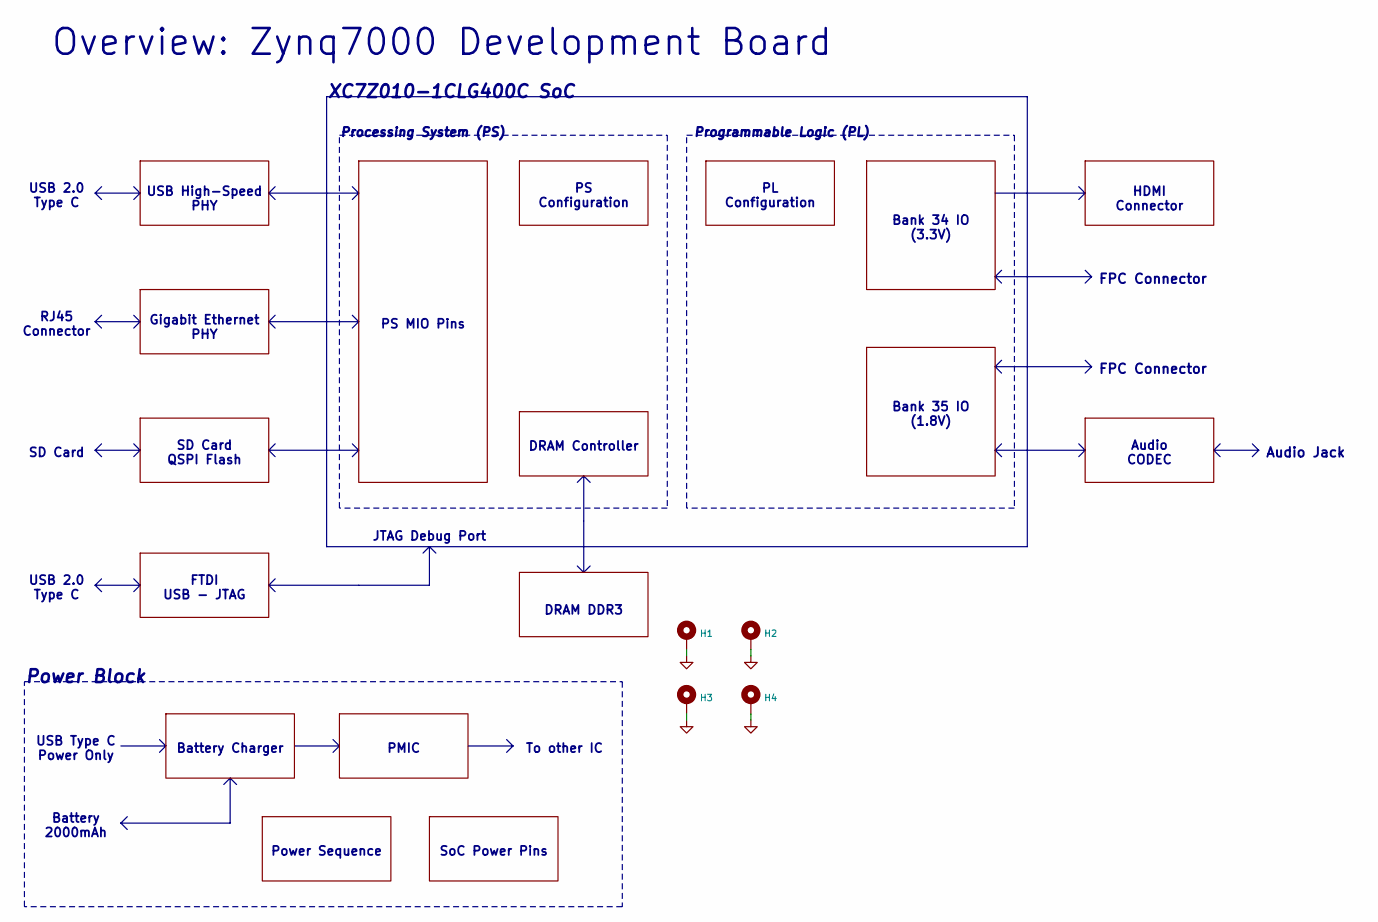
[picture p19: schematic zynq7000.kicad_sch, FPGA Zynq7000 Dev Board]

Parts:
H1, H2, H3, H4: MountingHole_Pad; MountingHole_3mm_Pad_Via

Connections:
GND: H1.1, H2.1, H3.1, H4.1; also elsewhere on the board

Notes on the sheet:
USB 2.0 Type C
Bank 34 IO (3.3V)
Processing System (PS)
FPC Connector
FTDI USB - JTAG
Audio Jack
PS Configuration
DRAM DDR3
Programmable Logic (PL)
Overview: Zynq7000 Development Board
To other IC
JTAG Debug Port
Power Block
SoC Power Pins
RJ45 Connector
USB Type C Power Only
PS MIO Pins
USB High-Speed PHY
Battery Charger
Gigabit Ethernet PHY
Power Sequence
HDMI Connector
Battery 2000mAh
PMIC
Audio CODEC
SD Card QSPI Flash
PL Configuration
Bank 35 IO (1.8V)
XC7Z010-1CLG400C SoC
DRAM Controller
SD Card

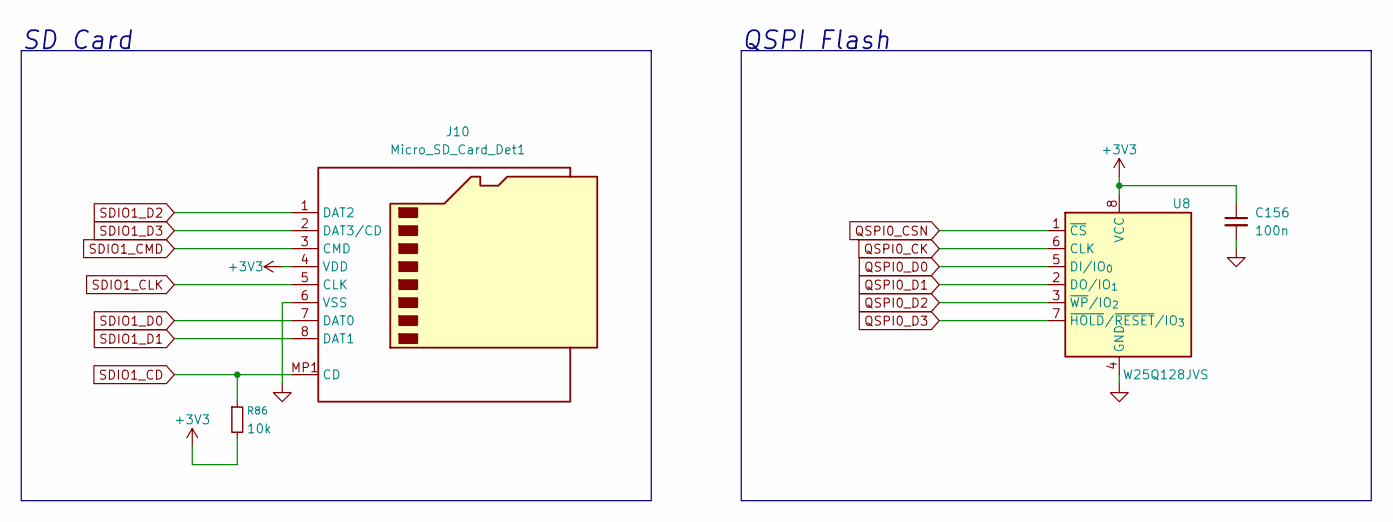
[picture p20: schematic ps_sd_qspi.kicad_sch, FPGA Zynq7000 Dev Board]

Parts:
C156: 100n; C_0402_1005Metric
J10: Micro_SD_Card_Det1; 5008730806
R86: 10k; R_0402_1005Metric
U8: W25Q128JVS; SOIC-8_5.3x5.3mm_P1.27mm

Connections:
+3V3: C156.1, J10.4 (VDD), R86.2, U8.8 (VCC); also elsewhere on the board
GND: C156.2, J10.6 (VSS), U8.4 (GND); also elsewhere on the board
QSPI0_CK: U8.6 (CLK); also elsewhere on the board
QSPI0_CSN: U8.1 (~CS); also elsewhere on the board
QSPI0_D0: U8.5 (DI/IO_{0}); also elsewhere on the board
QSPI0_D1: U8.2 (DO/IO_{1}); also elsewhere on the board
QSPI0_D2: U8.3 (~WP/IO_{2}); also elsewhere on the board
QSPI0_D3: U8.7 (~HOLD/~RESET/IO_{3}); also elsewhere on the board
SDIO1_CD: J10.MP1 (CD), R86.1; also elsewhere on the board
SDIO1_CLK: J10.5 (CLK); also elsewhere on the board
SDIO1_CMD: J10.3 (CMD); also elsewhere on the board
SDIO1_D0: J10.7 (DAT0); also elsewhere on the board
SDIO1_D1: J10.8 (DAT1); also elsewhere on the board
SDIO1_D2: J10.1 (DAT2); also elsewhere on the board
SDIO1_D3: J10.2 (DAT3/CD); also elsewhere on the board

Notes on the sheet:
QSPI Flash
SD Card

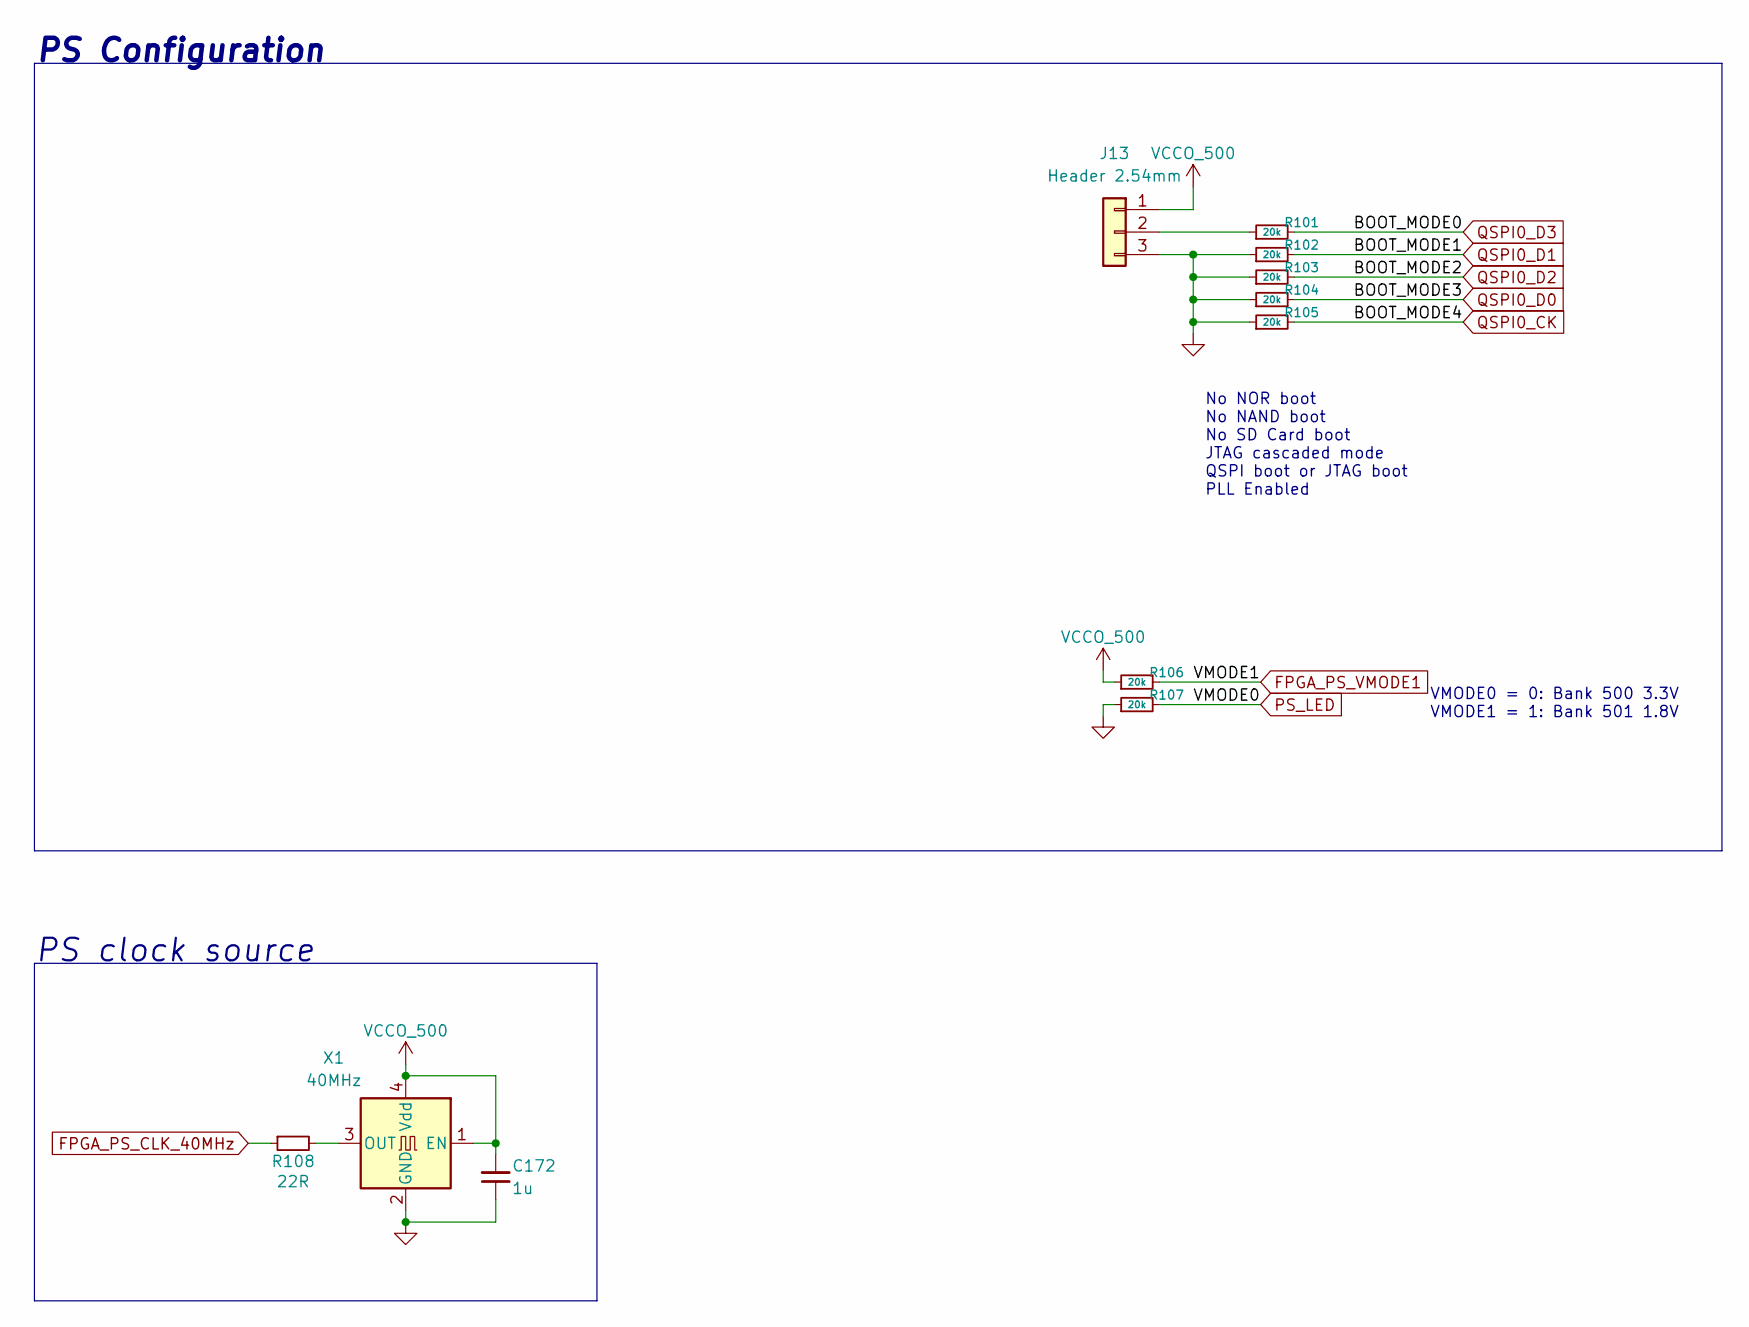
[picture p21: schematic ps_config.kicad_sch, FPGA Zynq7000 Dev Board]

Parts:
C172: 1u; C_0402_1005Metric
J13: Header 2.54mm; PinHeader_1x03_P2.54mm_Vertical
R101, R102, R103, R104, R105, R106, R107: 20k; R_0402_1005Metric
R108: 22R; R_0402_1005Metric
X1: 40MHz; Oscillator_SMD_Abracon_ASE-4Pin_3.2x2.5mm

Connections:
+3V3: C172.2, J13.1, R106.1, X1.1 (EN), X1.4 (Vdd); also elsewhere on the board
FPGA_PS_CLK_40MHz: R108.1; also elsewhere on the board
FPGA_PS_VMODE1: R106.2; also elsewhere on the board
GND: C172.1, J13.3, R102.1, R103.1, R104.1, R105.1, R107.1, X1.2 (GND); also elsewhere on the board
unnamed: J13.2, R101.1
unnamed: R108.2, X1.3 (OUT)
PS_LED: R107.2; also elsewhere on the board
QSPI0_CK: R105.2; also elsewhere on the board
QSPI0_D0: R104.2; also elsewhere on the board
QSPI0_D1: R102.2; also elsewhere on the board
QSPI0_D2: R103.2; also elsewhere on the board
QSPI0_D3: R101.2; also elsewhere on the board

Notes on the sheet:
PS clock source
VMODE0 = 0: Bank 500 3.3V VMODE1 = 1: Bank 501 1.8V
PS Configuration
No NOR boot No NAND boot No SD Card boot JTAG cascaded mode QSPI boot or JTAG boot PLL Enabled

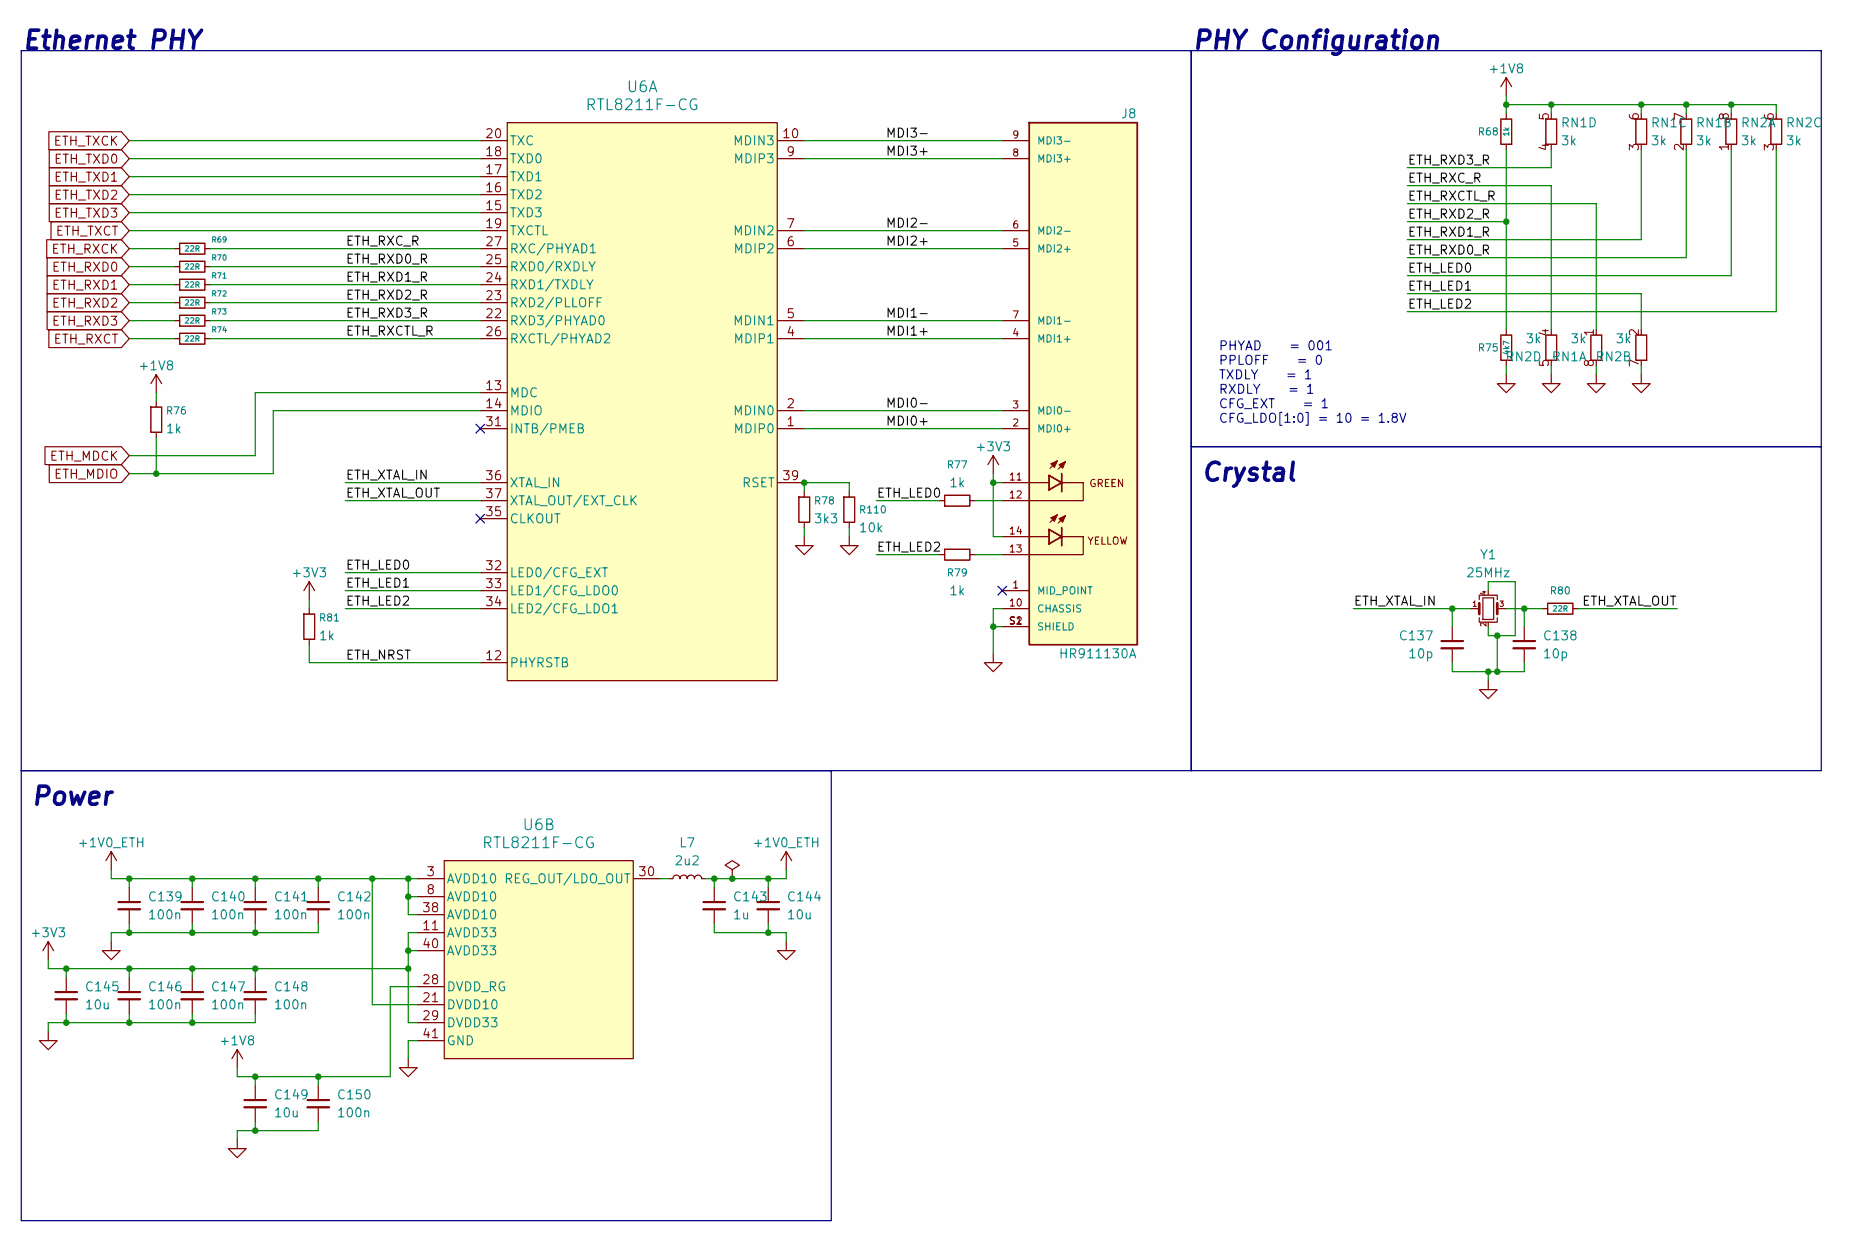
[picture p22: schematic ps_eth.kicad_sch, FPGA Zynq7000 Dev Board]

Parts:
C137, C138: 10p; C_0402_1005Metric
C139, C140, C141, C142, C146, C147, C148, C150: 100n; C_0402_1005Metric
C143: 1u; C_0402_1005Metric
C144, C145, C149: 10u; C_0402_1005Metric
J8: HR911130A; HANRUN_HR911130A; PARTREV A
L7: 2u2; L_1008_2520Metric
R68, R76, R77, R79, R81: 1k; R_0402_1005Metric
R69, R70, R71, R72, R73, R74, R80: 22R; R_0402_1005Metric
R75: 4k7; R_0402_1005Metric
R78: 3k3; R_0402_1005Metric
R110: 10k; R_0402_1005Metric
RN1, RN2: 3k; R_Array_Concave_4x0402
U6: RTL8211F-CG; QFN_40_7x7mm_RTL8211F
Y1: 25MHz; Crystal_SMD_3225-4Pin_3.2x2.5mm

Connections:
+1V0_ETH: C139.1, C140.1, C141.1, C142.1, C143.1, C144.1, L7.2, U6.3 (AVDD10), U6.8 (AVDD10), U6.21 (DVDD10), U6.38 (AVDD10)
+1V8: C149.1, C150.1, R68.2, R76.1, RN1.5 (R4.2), RN1.6 (R3.2), RN1.7 (R2.2), RN2.6 (R3.2), RN2.8, U6.28 (DVDD_RG); also elsewhere on the board
+3V3: C145.1, C146.1, C147.1, C148.1, J8.11, J8.14, R81.1, U6.11 (AVDD33), U6.29 (DVDD33), U6.40 (AVDD33); also elsewhere on the board
/Gigabit Ethernet PHY/ETH_LED0: R77.1, RN2.1, U6.32 (LED0/CFG_EXT)
/Gigabit Ethernet PHY/ETH_LED1: RN2.2 (R2.1), U6.33 (LED1/CFG_LDO0)
/Gigabit Ethernet PHY/ETH_LED2: R79.1, RN2.3 (R3.1), U6.34 (LED2/CFG_LDO1)
/Gigabit Ethernet PHY/ETH_NRST: R81.2, U6.12 (PHYRSTB)
/Gigabit Ethernet PHY/ETH_RXCTL_R: R74.2, RN1.1, U6.26 (RXCTL/PHYAD2)
/Gigabit Ethernet PHY/ETH_RXC_R: R69.2, RN2.4 (R4.1), U6.27 (RXC/PHYAD1)
/Gigabit Ethernet PHY/ETH_RXD0_R: R70.2, RN1.2 (R2.1), U6.25 (RXD0/RXDLY)
/Gigabit Ethernet PHY/ETH_RXD1_R: R71.2, RN1.3 (R3.1), U6.24 (RXD1/TXDLY)
/Gigabit Ethernet PHY/ETH_RXD2_R: R68.1, R72.2, R75.2, U6.23 (RXD2/PLLOFF)
/Gigabit Ethernet PHY/ETH_RXD3_R: R73.2, RN1.4 (R4.1), U6.22 (RXD3/PHYAD0)
/Gigabit Ethernet PHY/ETH_XTAL_IN: C137.1, U6.36 (XTAL_IN), Y1.1
/Gigabit Ethernet PHY/ETH_XTAL_OUT: R80.2, U6.37 (XTAL_OUT/EXT_CLK)
/Gigabit Ethernet PHY/MDI0+: J8.2 (MDI0+), U6.1 (MDIP0)
/Gigabit Ethernet PHY/MDI0-: J8.3 (MDI0-), U6.2 (MDIN0)
/Gigabit Ethernet PHY/MDI1+: J8.4 (MDI1+), U6.4 (MDIP1)
/Gigabit Ethernet PHY/MDI1-: J8.7 (MDI1-), U6.5 (MDIN1)
/Gigabit Ethernet PHY/MDI2+: J8.5 (MDI2+), U6.6 (MDIP2)
/Gigabit Ethernet PHY/MDI2-: J8.6 (MDI2-), U6.7 (MDIN2)
/Gigabit Ethernet PHY/MDI3+: J8.8 (MDI3+), U6.9 (MDIP3)
/Gigabit Ethernet PHY/MDI3-: J8.9 (MDI3-), U6.10 (MDIN3)
ETH_MDCK: U6.13 (MDC); also elsewhere on the board
ETH_MDIO: R76.2, U6.14 (MDIO); also elsewhere on the board
ETH_RXCK: R69.1; also elsewhere on the board
ETH_RXCT: R74.1; also elsewhere on the board
ETH_RXD0: R70.1; also elsewhere on the board
ETH_RXD1: R71.1; also elsewhere on the board
ETH_RXD2: R72.1; also elsewhere on the board
ETH_RXD3: R73.1; also elsewhere on the board
ETH_TXCK: U6.20 (TXC); also elsewhere on the board
ETH_TXCT: U6.19 (TXCTL); also elsewhere on the board
ETH_TXD0: U6.18 (TXD0); also elsewhere on the board
ETH_TXD1: U6.17 (TXD1); also elsewhere on the board
ETH_TXD2: U6.16 (TXD2); also elsewhere on the board
ETH_TXD3: U6.15 (TXD3); also elsewhere on the board
GND: C137.2, C138.2, C139.2, C140.2, C141.2, C142.2, C143.2, C144.2, C145.2, C146.2, C147.2, C148.2, C149.2, C150.2, J8.10 (CHASSIS), J8.S1 (SHIELD), J8.S2 (SHIELD), R75.1, R78.2, R110.2, RN1.8, RN2.5 (R4.2), RN2.7 (R2.2), U6.41 (GND), Y1.2, Y1.4; also elsewhere on the board
unnamed: C138.1, R80.1, Y1.3
unnamed: J8.12, R77.2
unnamed: J8.13, R79.2
unnamed: R78.1, R110.1, U6.39 (RSET)
unnamed: L7.1, U6.30 (REG_OUT/LDO_OUT)

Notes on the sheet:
Ethernet PHY
Crystal
PHY Configuration
Power
PHYAD = 001 PPLOFF = 0 TXDLY = 1 RXDLY = 1 CFG_EXT = 1 CFG_LDO[1:0] = 10 = 1.8V

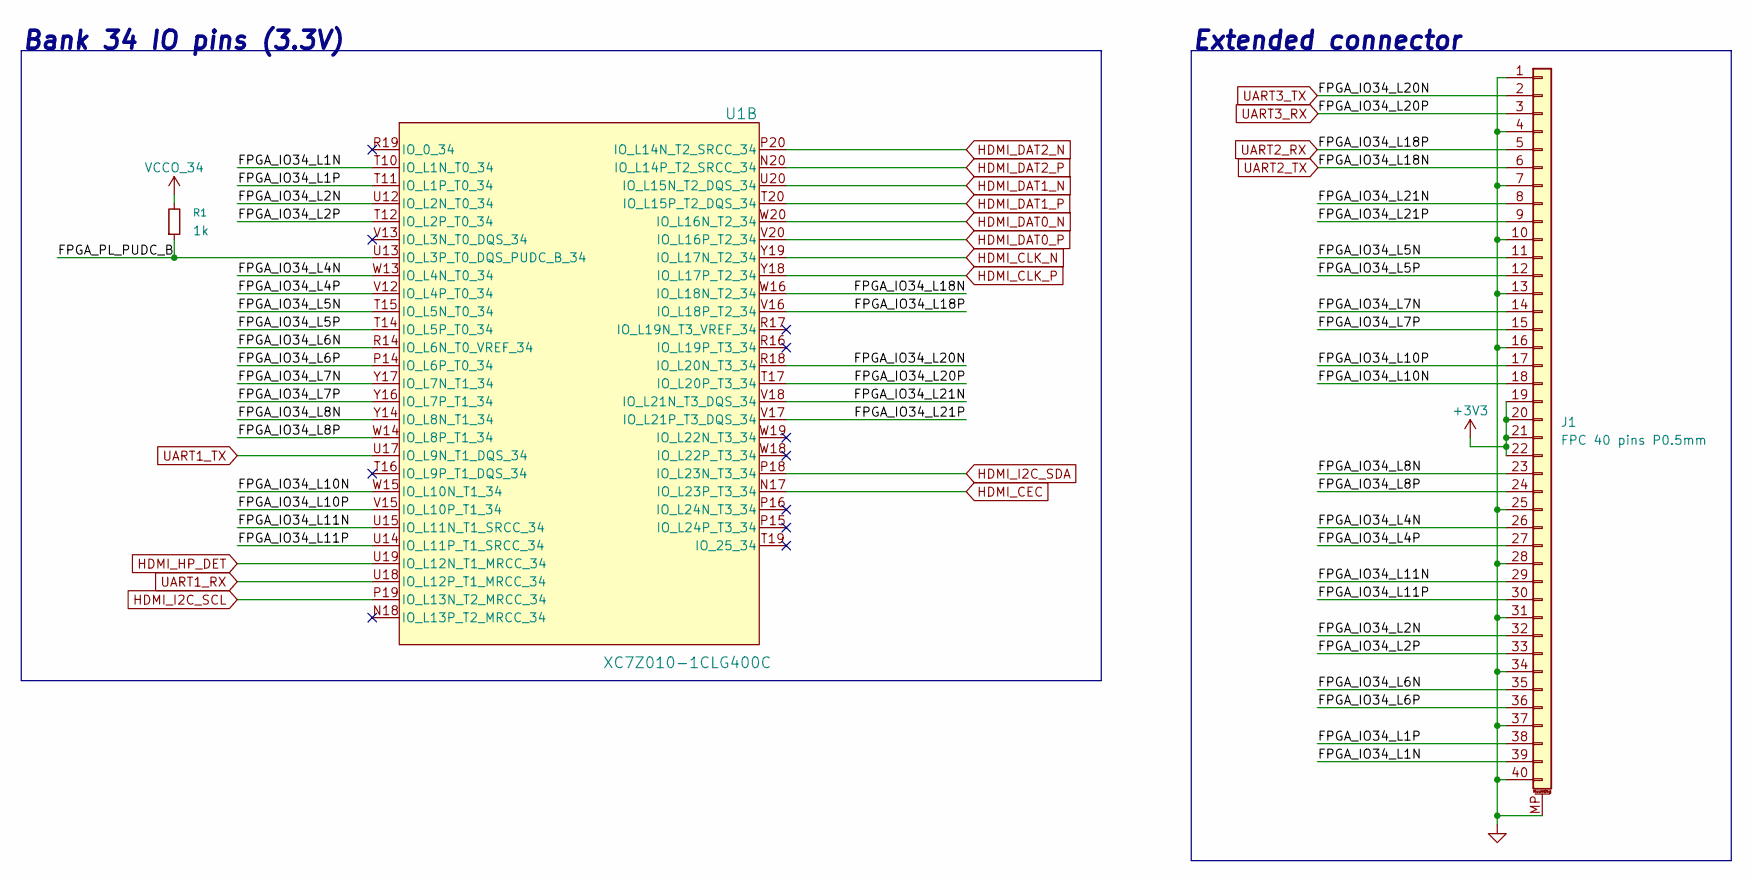
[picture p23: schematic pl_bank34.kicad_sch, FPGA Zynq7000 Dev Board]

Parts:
J1: FPC 40 pins P0.5mm; Amphenol_F32Q-1A7x1-11040_1x40-1MP_P0.5mm_Horizontal
R1: 1k; R_0402_1005Metric
U1: XC7Z010-1CLG400C; CLG400_XIL-L

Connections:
+3V3: J1.19, J1.20, J1.21, J1.22, R1.2; also elsewhere on the board
/Bank 34 (3.3V)/FPGA_IO34_L1N: J1.39, U1.T10 (IO_L1N_T0_34)
/Bank 34 (3.3V)/FPGA_IO34_L1P: J1.38, U1.T11 (IO_L1P_T0_34)
/Bank 34 (3.3V)/FPGA_IO34_L2N: J1.32, U1.U12 (IO_L2N_T0_34)
/Bank 34 (3.3V)/FPGA_IO34_L2P: J1.33, U1.T12 (IO_L2P_T0_34)
/Bank 34 (3.3V)/FPGA_IO34_L4N: J1.26, U1.W13 (IO_L4N_T0_34)
/Bank 34 (3.3V)/FPGA_IO34_L4P: J1.27, U1.V12 (IO_L4P_T0_34)
/Bank 34 (3.3V)/FPGA_IO34_L5N: J1.11, U1.T15 (IO_L5N_T0_34)
/Bank 34 (3.3V)/FPGA_IO34_L5P: J1.12, U1.T14 (IO_L5P_T0_34)
/Bank 34 (3.3V)/FPGA_IO34_L6N: J1.35, U1.R14 (IO_L6N_T0_VREF_34)
/Bank 34 (3.3V)/FPGA_IO34_L6P: J1.36, U1.P14 (IO_L6P_T0_34)
/Bank 34 (3.3V)/FPGA_IO34_L7N: J1.14, U1.Y17 (IO_L7N_T1_34)
/Bank 34 (3.3V)/FPGA_IO34_L7P: J1.15, U1.Y16 (IO_L7P_T1_34)
/Bank 34 (3.3V)/FPGA_IO34_L8N: J1.23, U1.Y14 (IO_L8N_T1_34)
/Bank 34 (3.3V)/FPGA_IO34_L8P: J1.24, U1.W14 (IO_L8P_T1_34)
/Bank 34 (3.3V)/FPGA_IO34_L10N: J1.18, U1.W15 (IO_L10N_T1_34)
/Bank 34 (3.3V)/FPGA_IO34_L10P: J1.17, U1.V15 (IO_L10P_T1_34)
/Bank 34 (3.3V)/FPGA_IO34_L11N: J1.29, U1.U15 (IO_L11N_T1_SRCC_34)
/Bank 34 (3.3V)/FPGA_IO34_L11P: J1.30, U1.U14 (IO_L11P_T1_SRCC_34)
/Bank 34 (3.3V)/FPGA_IO34_L21N: J1.8, U1.V18 (IO_L21N_T3_DQS_34)
/Bank 34 (3.3V)/FPGA_IO34_L21P: J1.9, U1.V17 (IO_L21P_T3_DQS_34)
/Bank 34 (3.3V)/FPGA_PL_PUDC_B: R1.1, U1.U13 (IO_L3P_T0_DQS_PUDC_B_34)
GND: J1.1, J1.4, J1.7, J1.10, J1.13, J1.16, J1.25, J1.28, J1.31, J1.34, J1.37, J1.40, J1.MP (MountPin); also elsewhere on the board
HDMI_CEC: U1.N17 (IO_L23P_T3_34); also elsewhere on the board
HDMI_CLK_N: U1.Y19 (IO_L17N_T2_34); also elsewhere on the board
HDMI_CLK_P: U1.Y18 (IO_L17P_T2_34); also elsewhere on the board
HDMI_DAT0_N: U1.W20 (IO_L16N_T2_34); also elsewhere on the board
HDMI_DAT0_P: U1.V20 (IO_L16P_T2_34); also elsewhere on the board
HDMI_DAT1_N: U1.U20 (IO_L15N_T2_DQS_34); also elsewhere on the board
HDMI_DAT1_P: U1.T20 (IO_L15P_T2_DQS_34); also elsewhere on the board
HDMI_DAT2_N: U1.P20 (IO_L14N_T2_SRCC_34); also elsewhere on the board
HDMI_DAT2_P: U1.N20 (IO_L14P_T2_SRCC_34); also elsewhere on the board
HDMI_HP_DET: U1.U19 (IO_L12N_T1_MRCC_34); also elsewhere on the board
HDMI_I2C_SCL: U1.P19 (IO_L13N_T2_MRCC_34); also elsewhere on the board
HDMI_I2C_SDA: U1.P18 (IO_L23N_T3_34); also elsewhere on the board
UART1_RX: U1.U18 (IO_L12P_T1_MRCC_34); also elsewhere on the board
UART1_TX: U1.U17 (IO_L9N_T1_DQS_34); also elsewhere on the board
UART2_RX: J1.5, U1.V16 (IO_L18P_T2_34); also elsewhere on the board
UART2_TX: J1.6, U1.W16 (IO_L18N_T2_34); also elsewhere on the board
UART3_RX: J1.3, U1.T17 (IO_L20P_T3_34); also elsewhere on the board
UART3_TX: J1.2, U1.R18 (IO_L20N_T3_34); also elsewhere on the board

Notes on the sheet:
Bank 34 IO pins (3.3V)
Extended connector

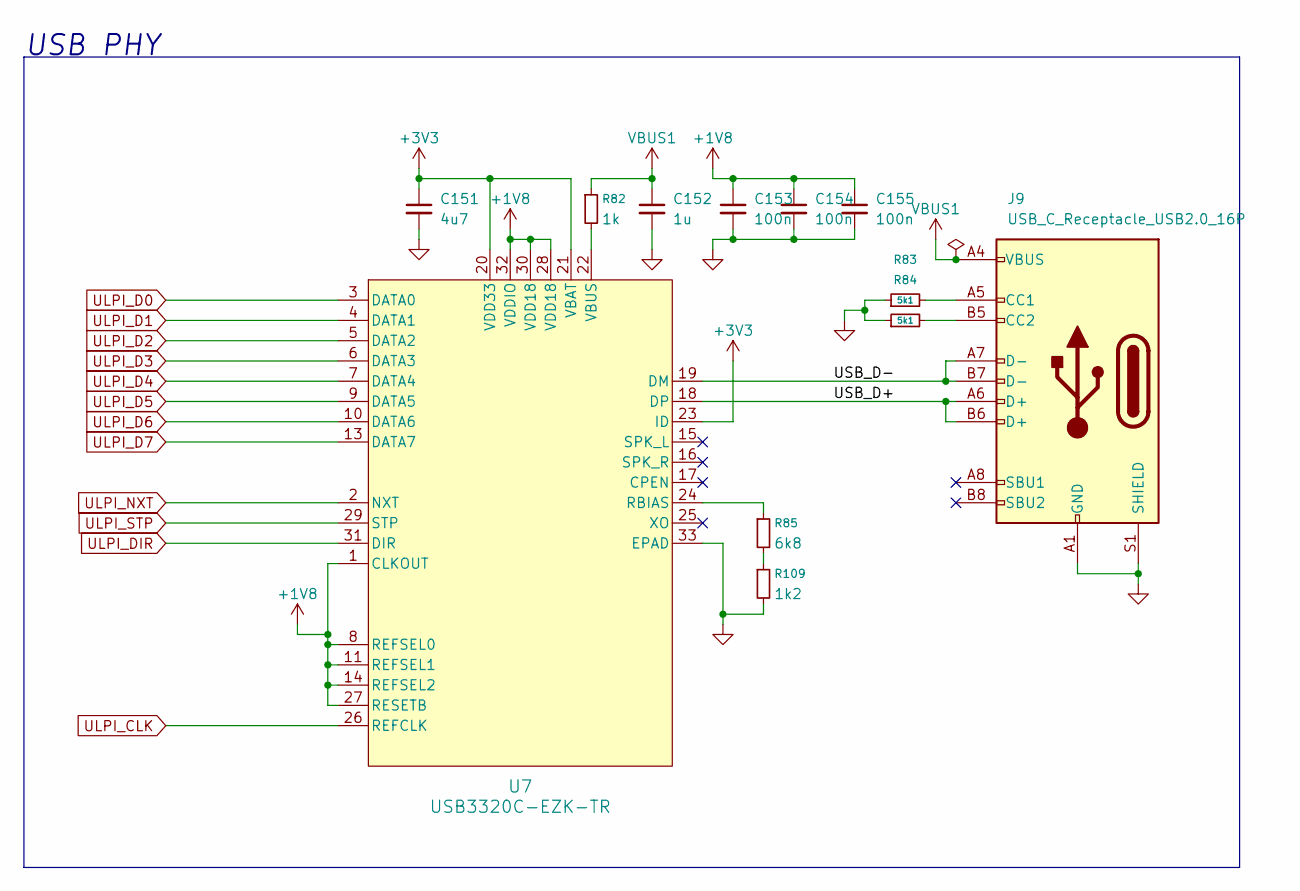
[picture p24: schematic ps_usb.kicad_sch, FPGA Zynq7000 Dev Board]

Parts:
C151: 4u7; C_0402_1005Metric
C152: 1u; C_0402_1005Metric
C153, C154, C155: 100n; C_0402_1005Metric
J9: USB_C_Receptacle_USB2.0_16P; USB_C_Receptacle_GCT_USB4105-xx-A_16P_TopMnt_Horizontal
R82: 1k; R_0402_1005Metric
R83, R84: 5k1; R_0402_1005Metric
R85: 6k8; R_0402_1005Metric
R109: 1k2; R_0402_1005Metric
U7: USB3320C-EZK-TR; QFN32_5X5_USB3320

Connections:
+1V8: C153.1, C154.1, C155.1, U7.1 (CLKOUT), U7.8 (REFSEL0), U7.11 (REFSEL1), U7.14 (REFSEL2), U7.27 (RESETB), U7.28 (VDD18), U7.30 (VDD18), U7.32 (VDDIO); also elsewhere on the board
+3V3: C151.1, U7.20 (VDD33), U7.21 (VBAT), U7.23 (ID); also elsewhere on the board
/USB HS PHY/USB_D+: J9.A6 (D+), J9.B6 (D+), U7.18 (DP)
/USB HS PHY/USB_D-: J9.A7 (D-), J9.B7 (D-), U7.19 (DM)
GND: C151.2, C152.2, C153.2, C154.2, C155.2, J9.A1 (GND), J9.A12 (GND), J9.B1 (GND), J9.B12 (GND), J9.S1 (SHIELD), R83.1, R84.1, R109.2, U7.33 (EPAD); also elsewhere on the board
unnamed: J9.A5 (CC1), R83.2
unnamed: J9.B5 (CC2), R84.2
unnamed: R85.2, R109.1
unnamed: R85.1, U7.24 (RBIAS)
unnamed: R82.2, U7.22 (VBUS)
ULPI_CLK: U7.26 (REFCLK); also elsewhere on the board
ULPI_D0: U7.3 (DATA0); also elsewhere on the board
ULPI_D1: U7.4 (DATA1); also elsewhere on the board
ULPI_D2: U7.5 (DATA2); also elsewhere on the board
ULPI_D3: U7.6 (DATA3); also elsewhere on the board
ULPI_D4: U7.7 (DATA4); also elsewhere on the board
ULPI_D5: U7.9 (DATA5); also elsewhere on the board
ULPI_D6: U7.10 (DATA6); also elsewhere on the board
ULPI_D7: U7.13 (DATA7); also elsewhere on the board
ULPI_DIR: U7.31 (DIR); also elsewhere on the board
ULPI_NXT: U7.2 (NXT); also elsewhere on the board
ULPI_STP: U7.29 (STP); also elsewhere on the board
VBUS1: C152.1, J9.A4 (VBUS), J9.A9 (VBUS), J9.B4 (VBUS), J9.B9 (VBUS), R82.1; also elsewhere on the board

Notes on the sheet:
USB PHY

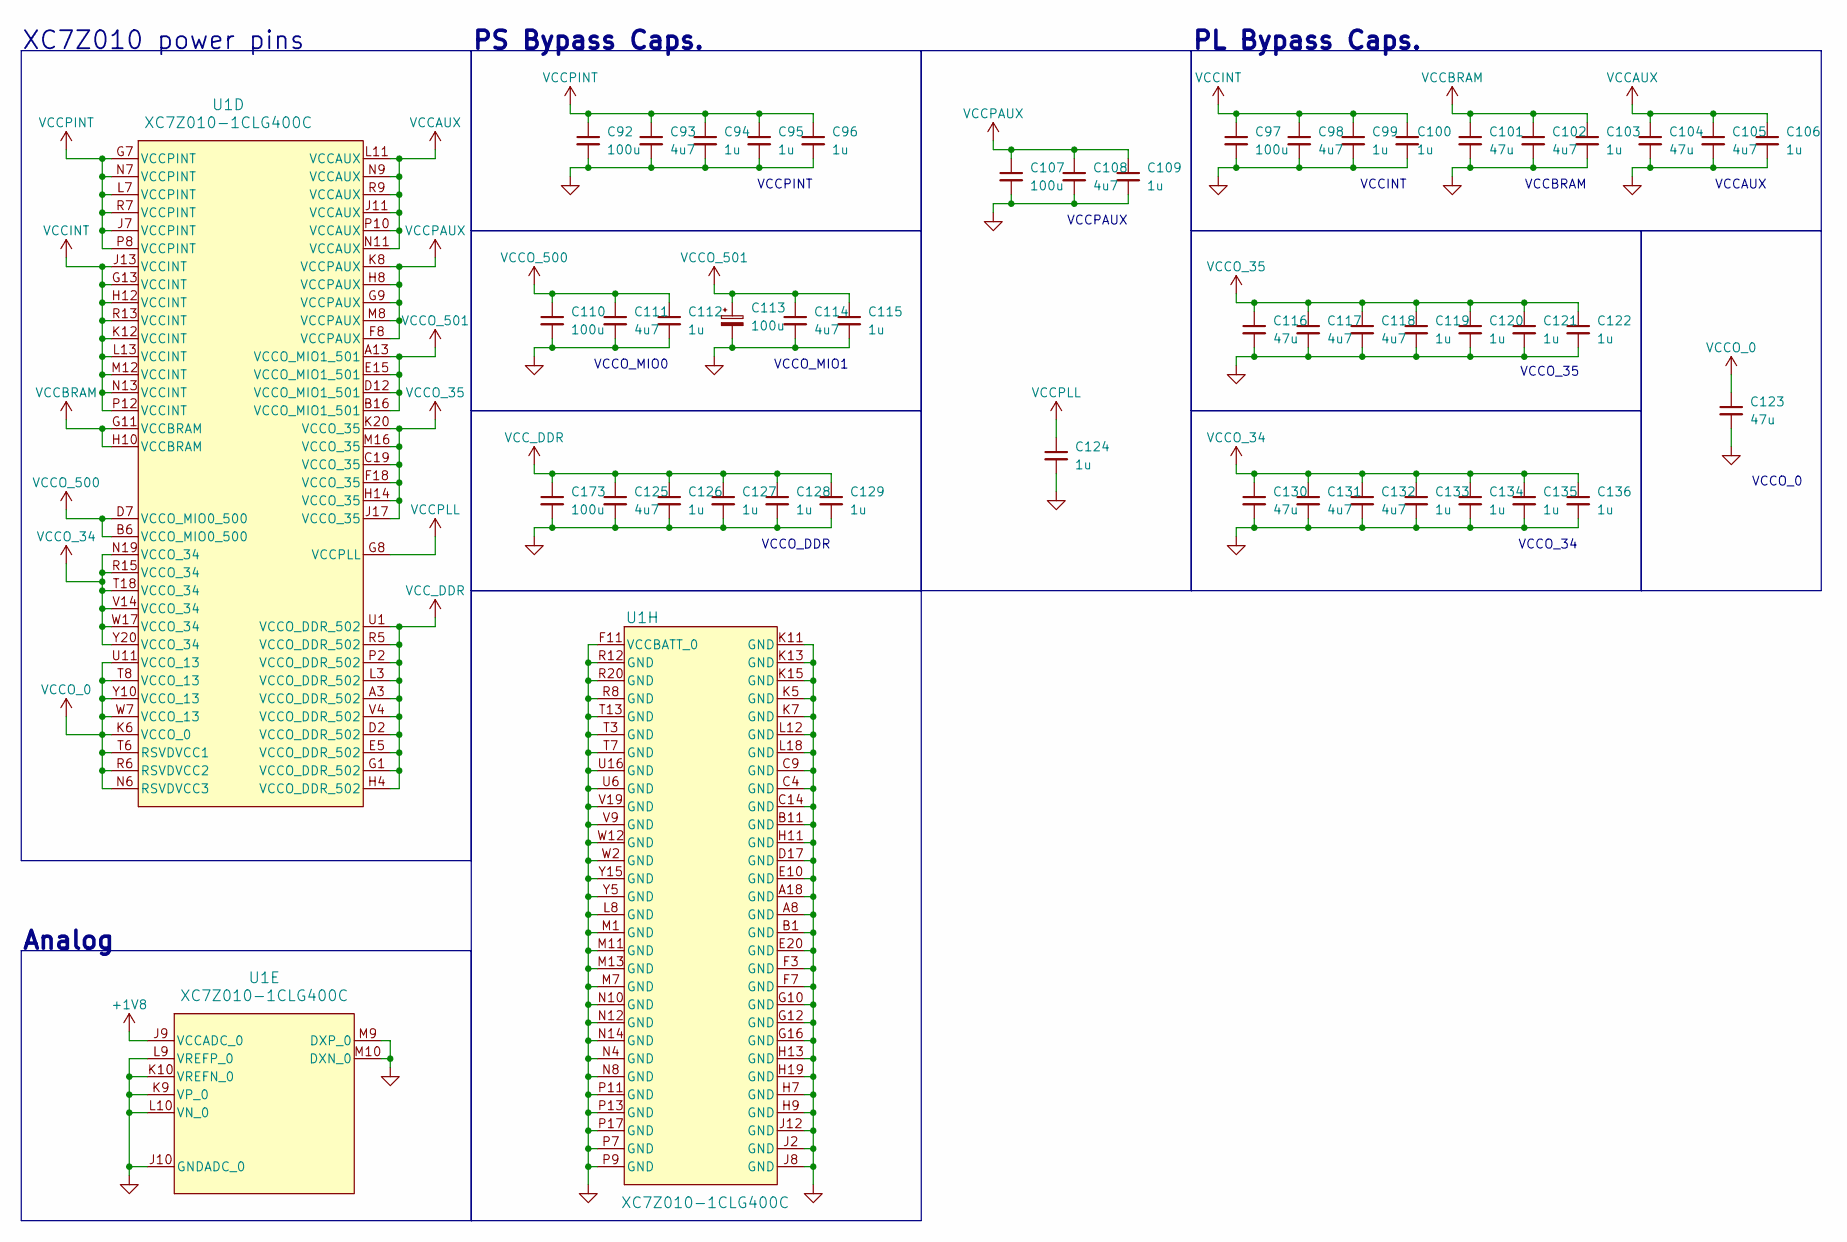
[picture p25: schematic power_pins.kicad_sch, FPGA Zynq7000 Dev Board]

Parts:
C92, C97, C107, C110, C113, C173: 100u; C_1206_3216Metric
C93, C98, C102, C105, C108, C111, C114, C117, C118, C125, C131, C132: 4u7; C_0402_1005Metric
C94, C95, C96, C99, C100, C103, C106, C109, C112, C115, C119, C120, C121, C122, C124, C126, C127, C128, C129, C133, C134, C135, C136: 1u; C_0402_1005Metric
C101, C104, C116, C123, C130: 47u; C_1206_3216Metric
U1: XC7Z010-1CLG400C; CLG400_XIL-L

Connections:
+1V0: C92.1, C93.1, C94.1, C95.1, C96.1, C97.1, C98.1, C99.1, C100.1, C101.1, C102.1, C103.1, U1.G7 (VCCPINT), U1.G11 (VCCBRAM), U1.G13 (VCCINT), U1.H10 (VCCBRAM), U1.H12 (VCCINT), U1.J7 (VCCPINT), U1.J13 (VCCINT), U1.K12 (VCCINT), U1.L7 (VCCPINT), U1.L13 (VCCINT), U1.M12 (VCCINT), U1.N7 (VCCPINT), U1.N13 (VCCINT), U1.P8 (VCCPINT), U1.P12 (VCCINT), U1.R7 (VCCPINT), U1.R13 (VCCINT); also elsewhere on the board
+1V8: C104.1, C105.1, C106.1, C107.1, C108.1, C109.1, C113.1, C114.1, C115.1, C116.1, C117.1, C118.1, C119.1, C120.1, C121.1, C122.1, C124.1, U1.A13 (VCCO_MIO1_501), U1.B16 (VCCO_MIO1_501), U1.C19 (VCCO_35), U1.D12 (VCCO_MIO1_501), U1.E15 (VCCO_MIO1_501), U1.F8 (VCCPAUX), U1.F18 (VCCO_35), U1.G8 (VCCPLL), U1.G9 (VCCPAUX), U1.H8 (VCCPAUX), U1.H14 (VCCO_35), U1.J9 (VCCADC_0), U1.J11 (VCCAUX), U1.J17 (VCCO_35), U1.K8 (VCCPAUX), U1.K20 (VCCO_35), U1.L11 (VCCAUX), U1.M8 (VCCPAUX), U1.M16 (VCCO_35), U1.N9 (VCCAUX), U1.N11 (VCCAUX), U1.P10 (VCCAUX), U1.R9 (VCCAUX); also elsewhere on the board
+1V35: C125.1, C126.1, C127.1, C128.1, C129.1, C173.1, U1.A3 (VCCO_DDR_502), U1.D2 (VCCO_DDR_502), U1.E5 (VCCO_DDR_502), U1.G1 (VCCO_DDR_502), U1.H4 (VCCO_DDR_502), U1.L3 (VCCO_DDR_502), U1.P2 (VCCO_DDR_502), U1.R5 (VCCO_DDR_502), U1.U1 (VCCO_DDR_502), U1.V4 (VCCO_DDR_502); also elsewhere on the board
+3V3: C110.1, C111.1, C112.1, C123.1, C130.1, C131.1, C132.1, C133.1, C134.1, C135.1, C136.1, U1.B6 (VCCO_MIO0_500), U1.D7 (VCCO_MIO0_500), U1.K6 (VCCO_0), U1.N6 (RSVDVCC3), U1.N19 (VCCO_34), U1.R6 (RSVDVCC2), U1.R15 (VCCO_34), U1.T6 (RSVDVCC1), U1.T8 (VCCO_13), U1.T18 (VCCO_34), U1.U11 (VCCO_13), U1.V14 (VCCO_34), U1.W7 (VCCO_13), U1.W17 (VCCO_34), U1.Y10 (VCCO_13), U1.Y20 (VCCO_34); also elsewhere on the board
GND: C92.2, C93.2, C94.2, C95.2, C96.2, C97.2, C98.2, C99.2, C100.2, C101.2, C102.2, C103.2, C104.2, C105.2, C106.2, C107.2, C108.2, C109.2, C110.2, C111.2, C112.2, C113.2, C114.2, C115.2, C116.2, C117.2, C118.2, C119.2, C120.2, C121.2, C122.2, C123.2, C124.2, C125.2, C126.2, C127.2, C128.2, C129.2, C130.2, C131.2, C132.2, C133.2, C134.2, C135.2, C136.2, C173.2, U1.A8 (GND), U1.A18 (GND), U1.B1 (GND), U1.B11 (GND), U1.C4 (GND), U1.C9 (GND), U1.C14 (GND), U1.D17 (GND), U1.E10 (GND), U1.E20 (GND), U1.F3 (GND), U1.F7 (GND), U1.F11 (VCCBATT_0), U1.G10 (GND), U1.G12 (GND), U1.G16 (GND), U1.H7 (GND), U1.H9 (GND), U1.H11 (GND), U1.H13 (GND), U1.H19 (GND), U1.J2 (GND), U1.J8 (GND), U1.J10 (GNDADC_0), U1.J12 (GND), U1.K5 (GND), U1.K7 (GND), U1.K9 (VP_0), U1.K10 (VREFN_0), U1.K11 (GND), U1.K13 (GND), U1.K15 (GND), U1.L8 (GND), U1.L9 (VREFP_0), U1.L10 (VN_0), U1.L12 (GND), U1.L18 (GND), U1.M1 (GND), U1.M7 (GND), U1.M9 (DXP_0), U1.M10 (DXN_0), U1.M11 (GND), U1.M13 (GND), U1.N4 (GND), U1.N8 (GND), U1.N10 (GND), U1.N12 (GND), U1.N14 (GND), U1.P7 (GND), U1.P9 (GND), U1.P11 (GND), U1.P13 (GND), U1.P17 (GND), U1.R8 (GND), U1.R12 (GND), U1.R20 (GND), U1.T3 (GND), U1.T7 (GND), U1.T13 (GND), U1.U6 (GND), U1.U16 (GND), U1.V9 (GND), U1.V19 (GND), U1.W2 (GND), U1.W12 (GND), U1.Y5 (GND), U1.Y15 (GND); also elsewhere on the board

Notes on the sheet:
XC7Z010 power pins
VCCPAUX
VCCO_MIO0
Analog
VCCO_0
VCCO_35
VCCO_DDR
VCCINT
VCCO_34
PS Bypass Caps.
VCCAUX
VCCBRAM
PL Bypass Caps.
VCCO_MIO1
VCCPINT

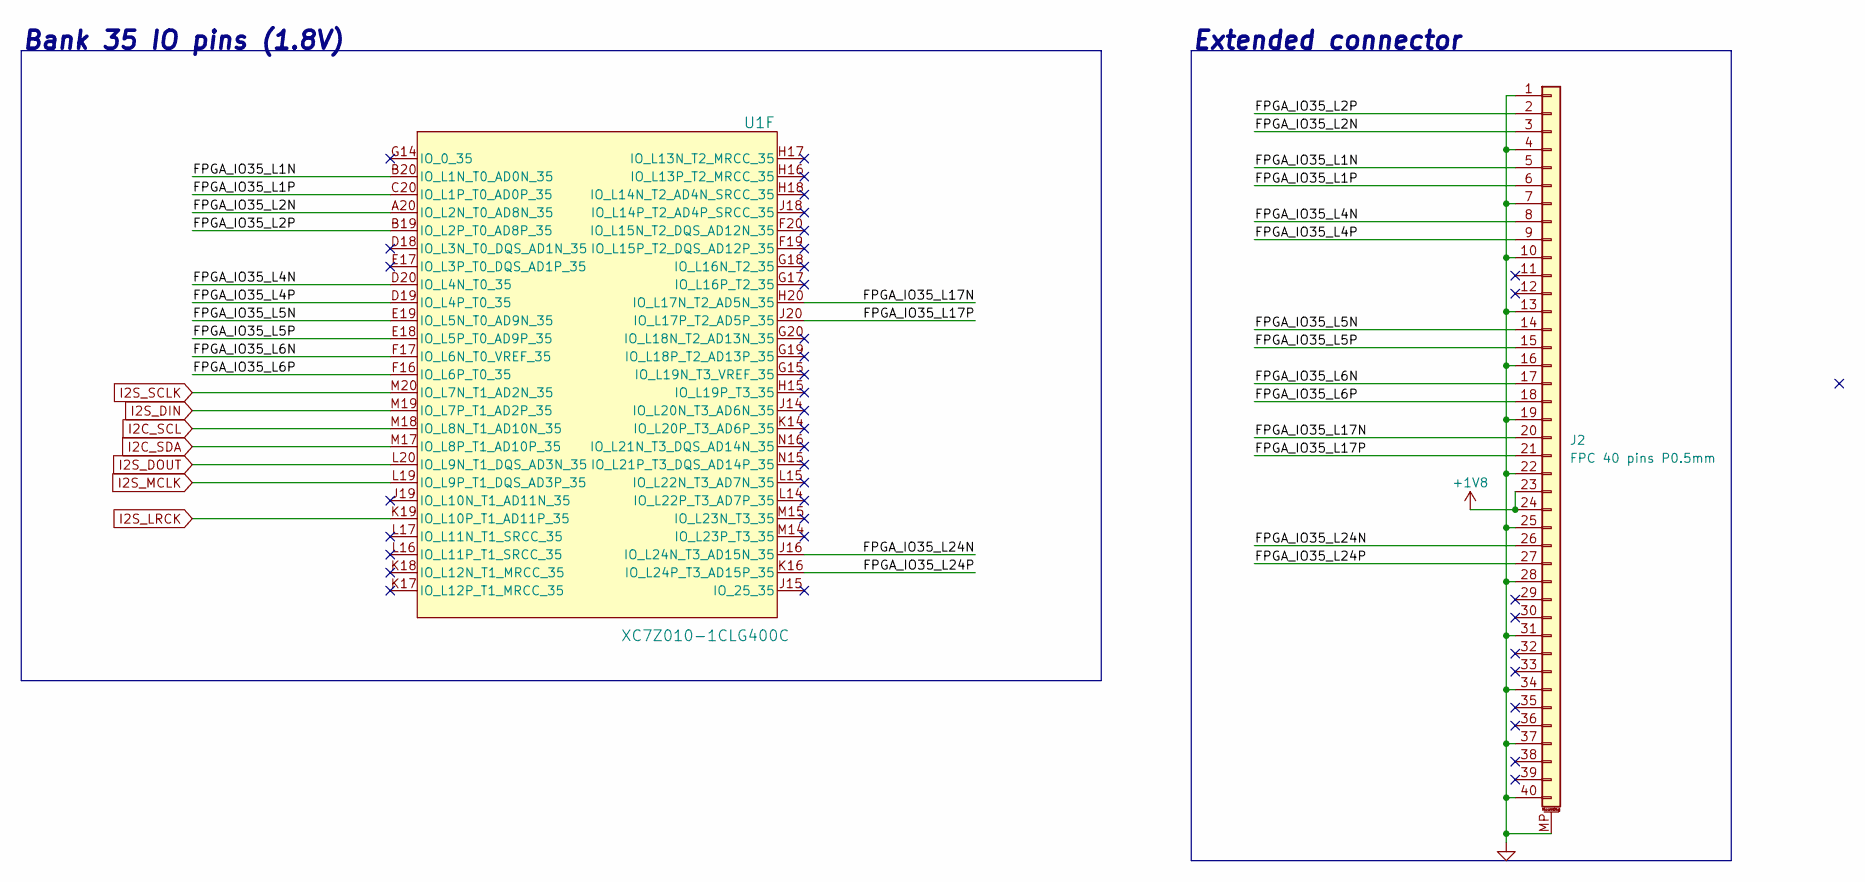
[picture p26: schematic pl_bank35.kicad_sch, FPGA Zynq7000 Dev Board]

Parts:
J2: FPC 40 pins P0.5mm; Amphenol_F32Q-1A7x1-11040_1x40-1MP_P0.5mm_Horizontal
U1: XC7Z010-1CLG400C; CLG400_XIL-L

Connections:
+1V8: J2.23, J2.24; also elsewhere on the board
/Bank 35 (1.8V)/FPGA_IO35_L1N: J2.5, U1.B20 (IO_L1N_T0_AD0N_35)
/Bank 35 (1.8V)/FPGA_IO35_L1P: J2.6, U1.C20 (IO_L1P_T0_AD0P_35)
/Bank 35 (1.8V)/FPGA_IO35_L2N: J2.3, U1.A20 (IO_L2N_T0_AD8N_35)
/Bank 35 (1.8V)/FPGA_IO35_L2P: J2.2, U1.B19 (IO_L2P_T0_AD8P_35)
/Bank 35 (1.8V)/FPGA_IO35_L4N: J2.8, U1.D20 (IO_L4N_T0_35)
/Bank 35 (1.8V)/FPGA_IO35_L4P: J2.9, U1.D19 (IO_L4P_T0_35)
/Bank 35 (1.8V)/FPGA_IO35_L5N: J2.14, U1.E19 (IO_L5N_T0_AD9N_35)
/Bank 35 (1.8V)/FPGA_IO35_L5P: J2.15, U1.E18 (IO_L5P_T0_AD9P_35)
/Bank 35 (1.8V)/FPGA_IO35_L6N: J2.17, U1.F17 (IO_L6N_T0_VREF_35)
/Bank 35 (1.8V)/FPGA_IO35_L6P: J2.18, U1.F16 (IO_L6P_T0_35)
/Bank 35 (1.8V)/FPGA_IO35_L17N: J2.20, U1.H20 (IO_L17N_T2_AD5N_35)
/Bank 35 (1.8V)/FPGA_IO35_L17P: J2.21, U1.J20 (IO_L17P_T2_AD5P_35)
/Bank 35 (1.8V)/FPGA_IO35_L24N: J2.26, U1.J16 (IO_L24N_T3_AD15N_35)
/Bank 35 (1.8V)/FPGA_IO35_L24P: J2.27, U1.K16 (IO_L24P_T3_AD15P_35)
GND: J2.1, J2.4, J2.7, J2.10, J2.13, J2.16, J2.19, J2.22, J2.25, J2.28, J2.31, J2.34, J2.37, J2.40, J2.MP (MountPin); also elsewhere on the board
I2C_SCL: U1.M18 (IO_L8N_T1_AD10N_35); also elsewhere on the board
I2C_SDA: U1.M17 (IO_L8P_T1_AD10P_35); also elsewhere on the board
I2S_DIN: U1.M19 (IO_L7P_T1_AD2P_35); also elsewhere on the board
I2S_DOUT: U1.L20 (IO_L9N_T1_DQS_AD3N_35); also elsewhere on the board
I2S_LRCK: U1.K19 (IO_L10P_T1_AD11P_35); also elsewhere on the board
I2S_MCLK: U1.L19 (IO_L9P_T1_DQS_AD3P_35); also elsewhere on the board
I2S_SCLK: U1.M20 (IO_L7N_T1_AD2N_35); also elsewhere on the board

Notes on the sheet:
Extended connector
Bank 35 IO pins (1.8V)

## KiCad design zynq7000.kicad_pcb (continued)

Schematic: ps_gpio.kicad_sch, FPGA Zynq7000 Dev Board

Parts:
C47: 100n; C_0402_1005Metric
D4: RED; LED_0603_1608Metric
R44, R45, R46, R47, R48, R49: 22R; R_0402_1005Metric
R50, R51: 4k7; R_0402_1005Metric
R52: 1k; R_0402_1005Metric
U1: XC7Z010-1CLG400C; CLG400_XIL-L

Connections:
+1V8: R50.1; also elsewhere on the board
/PS IO pins/ETH_TXCTL_R: R49.1, U1.F14 (PS_MIO21_501)
/PS IO pins/ETH_TXC_R: R44.1, U1.A19 (PS_MIO16_501)
/PS IO pins/ETH_TXD0_R: R45.1, U1.E14 (PS_MIO17_501)
/PS IO pins/ETH_TXD1_R: R46.1, U1.B18 (PS_MIO18_501)
/PS IO pins/ETH_TXD2_R: R47.1, U1.D10 (PS_MIO19_501)
/PS IO pins/ETH_TXD3_R: R48.1, U1.A17 (PS_MIO20_501)
ETH_MDCK: U1.C10 (PS_MIO52_501); also elsewhere on the board
ETH_MDIO: U1.C11 (PS_MIO53_501); also elsewhere on the board
ETH_RXCK: U1.B17 (PS_MIO22_501); also elsewhere on the board
ETH_RXCT: U1.D13 (PS_MIO27_501); also elsewhere on the board
ETH_RXD0: U1.D11 (PS_MIO23_501); also elsewhere on the board
ETH_RXD1: U1.A16 (PS_MIO24_501); also elsewhere on the board
ETH_RXD2: U1.F15 (PS_MIO25_501); also elsewhere on the board
ETH_RXD3: U1.A15 (PS_MIO26_501); also elsewhere on the board
ETH_TXCK: R44.2; also elsewhere on the board
ETH_TXCT: R49.2; also elsewhere on the board
ETH_TXD0: R45.2; also elsewhere on the board
ETH_TXD1: R46.2; also elsewhere on the board
ETH_TXD2: R47.2; also elsewhere on the board
ETH_TXD3: R48.2; also elsewhere on the board
FPGA_PS_VMODE1: U1.D5 (PS_MIO8_500); also elsewhere on the board
GND: C47.2, D4.1 (K), R51.2; also elsewhere on the board
unnamed: D4.2 (A), R52.2
unnamed: C47.1, R50.2, R51.1, U1.E11 (PS_MIO_VREF_501)
PS_LED: R52.1, U1.D8 (PS_MIO7_500); also elsewhere on the board
QSPI0_CK: U1.A5 (PS_MIO6_500); also elsewhere on the board
QSPI0_CSN: U1.A7 (PS_MIO1_500); also elsewhere on the board
QSPI0_D0: U1.B8 (PS_MIO2_500); also elsewhere on the board
QSPI0_D1: U1.D6 (PS_MIO3_500); also elsewhere on the board
QSPI0_D2: U1.B7 (PS_MIO4_500); also elsewhere on the board
QSPI0_D3: U1.A6 (PS_MIO5_500); also elsewhere on the board
SDIO1_CD: U1.E6 (PS_MIO0_500); also elsewhere on the board
SDIO1_CLK: U1.D9 (PS_MIO12_500); also elsewhere on the board
SDIO1_CMD: U1.C6 (PS_MIO11_500); also elsewhere on the board
SDIO1_D0: U1.E9 (PS_MIO10_500); also elsewhere on the board
SDIO1_D1: U1.E8 (PS_MIO13_500); also elsewhere on the board
SDIO1_D2: U1.C5 (PS_MIO14_500); also elsewhere on the board
SDIO1_D3: U1.C8 (PS_MIO15_500); also elsewhere on the board
ULPI_CLK: U1.B12 (PS_MIO48_501); also elsewhere on the board
ULPI_D0: U1.F13 (PS_MIO44_501); also elsewhere on the board
ULPI_D1: U1.B15 (PS_MIO45_501); also elsewhere on the board
ULPI_D2: U1.D16 (PS_MIO46_501); also elsewhere on the board
ULPI_D3: U1.B14 (PS_MIO47_501); also elsewhere on the board
ULPI_D4: U1.D14 (PS_MIO40_501); also elsewhere on the board
ULPI_D5: U1.C12 (PS_MIO49_501); also elsewhere on the board
ULPI_D6: U1.B13 (PS_MIO50_501); also elsewhere on the board
ULPI_D7: U1.B9 (PS_MIO51_501); also elsewhere on the board
ULPI_DIR: U1.C17 (PS_MIO41_501); also elsewhere on the board
ULPI_NXT: U1.A9 (PS_MIO43_501); also elsewhere on the board
ULPI_STP: U1.E12 (PS_MIO42_501); also elsewhere on the board

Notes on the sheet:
PS IO pins

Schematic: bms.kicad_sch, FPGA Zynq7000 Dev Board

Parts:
C85, C88, C90, C91: 4u7; C_0402_1005Metric
C86: 47n; C_0402_1005Metric
C87: 10u; C_0603_1608Metric
C89: 10u; C_0402_1005Metric
D5: BLUE; LED_0603_1608Metric
D6: GREEN; LED_0603_1608Metric
J6: USB_C_Receptacle_USB2.0_16P; USB_C_Receptacle_GCT_USB4105-xx-A_16P_TopMnt_Horizontal
J7: MX_1.25mm; Molex_PicoBlade_53398-0671_1x06-1MP_P1.25mm_Vertical
L6: 1u; L_Chilisin_BMRA00040420
R61, R62, R66: 5k1; R_0402_1005Metric
R63: 0R; R_0402_1005Metric; not fitted
R64, R65: 2k2; R_0402_1005Metric
R67: 30k; R_0402_1005Metric
U5: BQ25601; WQFN-24-1EP_4x4mm_P0.5mm_BQ25601

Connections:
+BATT: C89.1, J7.1, J7.2, U5.13 (BAT), U5.14 (BAT)
/BMS/BATT_THER: J7.5, R66.2, R67.1, U5.11 (TS)
GND: C85.2, C87.2, C88.2, C89.2, C90.2, C91.2, J6.A1 (GND), J6.A12 (GND), J6.B1 (GND), J6.B12 (GND), J6.S1 (SHIELD), J7.3, J7.4, R61.1, R62.1, R67.2, U5.2 (PSEL), U5.9 (~CE), U5.17 (GND), U5.18 (GND), U5.25 (GND); also elsewhere on the board
unnamed: C86.1, L6.1, U5.19 (SW), U5.20 (SW)
unnamed: D5.1 (K), R64.2
unnamed: D6.1 (K), R65.1
unnamed: J6.A5 (CC1), R61.2
unnamed: J6.B5 (CC2), R62.2
unnamed: J6.A6 (D+), J6.B6 (D+), R63.2
unnamed: J6.A7 (D-), J6.B7 (D-), R63.1
unnamed: C86.2, U5.21 (BTST)
unnamed: C90.1, C91.1, U5.23 (PMID)
unnamed: C88.1, R66.1, U5.22 (REGN)
unnamed: R64.1, U5.4 (STAT)
unnamed: R65.2, U5.3 (~PG)
PMIC_I2C_SCL: U5.5 (SCL); also elsewhere on the board
PMIC_I2C_SDA: U5.6 (SDA); also elsewhere on the board
PMIC_PWRON: U5.12 (~QON); also elsewhere on the board
VBUS: C85.1, J6.A4 (VBUS), J6.A9 (VBUS), J6.B4 (VBUS), J6.B9 (VBUS), U5.1 (VAC), U5.24 (VBUS)
VSYS: C87.1, D5.2 (A), D6.2 (A), L6.2, U5.15 (SYS), U5.16 (SYS); also elsewhere on the board

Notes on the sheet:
PSEL = 0 : ILIM = 2.4A CE = 0 : charge enable PMIC_PWRON = 0 for 1s: BATFET turn on. PMIC turn on. PMIC_PWRON = 0 for 4s: PMIC turn off. PMIC_PWRON = 0 for 8s: system reset.
BMS

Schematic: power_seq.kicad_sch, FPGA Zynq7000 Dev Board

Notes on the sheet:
+1.0V
From PMIC
BUCK
+3.3V
1.4A
LDO
PS: AUX, PLL, Bank 501 PL: AUX, Bank 35 USB PHY, ETH PHY, Audio CODEC
6A discharge 2A charge
4.5A
PS: Bank 502 2xDDR3 DRAM
0.5A
0.8A
+1.35V
+0.675V
DDR3L VTT rail
From BMS
Power Sequence
Power up: 1 -> 2 -> 3 -> 4 Power down: 4 -> 3 -> 2 -> 1
USB-C Connector
+5V
+1.8V
1.25A
0.2A
Power Tree
PS: Bank 500 PL: Bank 34 QSPI Flash, SD Card
DDR3L reference
1.1A
Ramp-up time must be smaller than 50ms
BMS
Battery
+3.5V -> +4.2V
0.6A
+3.5V
PS: Internal PL: Internal, BRAM
3.5V
3.8A
Audio CODEC

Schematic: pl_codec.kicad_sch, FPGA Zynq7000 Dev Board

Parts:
C48, C49, C50, C51, C54: 100n; C_0402_1005Metric
C52, C53, C55: 1u; C_0402_1005Metric
C56, C57: 22u; C_0603_1608Metric
J4: PJ320D; Jack_3.5mm_PJ320D_Horizontal
R53: 2k2; R_0402_1005Metric
R54, R55: 4k7; R_0402_1005Metric
U4: SGTL5000XNLA3; QFN-20-1EP_3x3mm_P0.4mm_EP1.65x1.65mm

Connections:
+1V8: C48.1, C49.1, R54.1, R55.1, U4.12 (VDDIO), U4.20 (VDDD); also elsewhere on the board
+1V8A: C50.1, U4.3 (VDDA); also elsewhere on the board
/Audio CODEC/LINEIN_L: C53.1, C57.2, J4.T
/Audio CODEC/LINEIN_R: C52.1, C56.2, J4.R1
/Audio CODEC/MIC_IN: C54.1, J4.S, R53.1
GND: C48.2, C49.2, C50.2, C51.1, C55.2, U4.21 (GND); also elsewhere on the board
I2C_SCL: R55.2, U4.19 (CTRL_CLK); also elsewhere on the board
I2C_SDA: R54.2, U4.18 (CTRL_DATA); also elsewhere on the board
I2S_DIN: U4.17 (I2S_DIN); also elsewhere on the board
I2S_DOUT: U4.16 (I2S_DOUT); also elsewhere on the board
I2S_LRCK: U4.14 (I2S_LRCLK); also elsewhere on the board
I2S_MCLK: U4.13 (SYS_MCLK); also elsewhere on the board
I2S_SCLK: U4.15 (I2S_SCLK); also elsewhere on the board
unnamed: C57.1, U4.4 (HP_L)
unnamed: C56.1, U4.1 (HP_R)
unnamed: J4.R2, U4.2 (HP_VGND)
unnamed: C53.2, U4.9 (LINEIN_L)
unnamed: C52.2, U4.8 (LINEIN_R)
unnamed: C54.2, U4.10 (MIC)
unnamed: C55.1, R53.2, U4.11 (MIC_BIAS)
unnamed: C51.2, U4.5 (VAG)

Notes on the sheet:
Audio CODEC

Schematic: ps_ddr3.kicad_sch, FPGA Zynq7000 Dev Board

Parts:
C1, C2, C3, C4, C5, C6, C7, C8, C10, C11, C12, C13, C14, C15, C16, C17, C18, C19, C20, C21, C22, C23, C24, C25, C26: 1u; C_0402_1005Metric
C9: 470n; C_0402_1005Metric; not fitted
C29, C30: 10u; C_0402_1005Metric
C31, C32: 4u7; C_0402_1005Metric
C33, C34, C35, C36, C37, C38, C39, C40, C41, C42, C43, C44: 100n; C_0402_1005Metric
R3, R4: 240R; R_0402_1005Metric
R6, R7, R8: 4k7; R_0402_1005Metric
R9, R10, R11, R12, R13, R14, R15, R16, R17, R18, R20, R21, R22, R23, R24, R25, R26, R27, R28, R29, R30, R31, R32, R33: 60R4; R_0402_1005Metric
R19: 120R; R_0402_1005Metric
U2, U3: H5TC2G83EFR-xxA; FBGA-78_7.5x11mm_Layout2x3x13_P0.8mm

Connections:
+0V675: C29.1, C30.1, C31.1, C32.1, C33.1, C34.1, C35.1, C36.1, C37.1, C38.1, C39.1, C40.1, C41.1, C42.1, C43.1, C44.1, R9.1, R10.1, R11.1, R12.1, R13.1, R14.1, R15.1, R16.1, R17.1, R18.1, R20.1, R21.1, R22.1, R23.1, R24.1, R25.1, R26.1, R27.1, R28.1, R29.1, R30.1, R31.1, R32.1, R33.1; also elsewhere on the board
+1V35: C1.1, C2.1, C3.1, C4.1, C5.1, C6.1, C7.1, C8.1, C9.1, C10.1, C11.1, C12.1, C13.1, C14.1, C15.1, C16.1, C17.1, C18.1, C19.1, C20.1, C21.1, C22.1, C23.1, C24.1, U2.A2 (VDD), U2.A9 (VDD), U2.B9 (VDDQ), U2.C1 (VDDQ), U2.D7 (VDD), U2.E2 (VDDQ), U2.E9 (VDDQ), U2.G2 (VDD), U2.G8 (VDD), U2.K1 (VDD), U2.K9 (VDD), U2.M1 (VDD), U2.M9 (VDD), U3.A2 (VDD), U3.A9 (VDD), U3.B9 (VDDQ), U3.C1 (VDDQ), U3.D7 (VDD), U3.E2 (VDDQ), U3.E9 (VDDQ), U3.G2 (VDD), U3.G8 (VDD), U3.K1 (VDD), U3.K9 (VDD), U3.M1 (VDD), U3.M9 (VDD); also elsewhere on the board
DRAM_A0: R16.2, U2.K3 (A0), U3.K3 (A0); also elsewhere on the board
DRAM_A1: R18.2, U2.L7 (A1), U3.L7 (A1); also elsewhere on the board
DRAM_A2: R21.2, U2.L3 (A2), U3.L3 (A2); also elsewhere on the board
DRAM_A3: R23.2, U2.K2 (A3), U3.K2 (A3); also elsewhere on the board
DRAM_A4: R25.2, U2.L8 (A4), U3.L8 (A4); also elsewhere on the board
DRAM_A5: R27.2, U2.L2 (A5), U3.L2 (A5); also elsewhere on the board
DRAM_A6: R29.2, U2.M8 (A6), U3.M8 (A6); also elsewhere on the board
DRAM_A7: R31.2, U2.M2 (A7), U3.M2 (A7); also elsewhere on the board
DRAM_A8: R33.2, U2.N8 (A8), U3.N8 (A8); also elsewhere on the board
DRAM_A9: R9.2, U2.M3 (A9), U3.M3 (A9); also elsewhere on the board
DRAM_A10: R11.2, U2.H7 (A10/AP), U3.H7 (A10/AP); also elsewhere on the board
DRAM_A11: R13.2, U2.M7 (A11), U3.M7 (A11); also elsewhere on the board
DRAM_A12: R15.2, U2.K7 (A12/BC#), U3.K7 (A12/BC#); also elsewhere on the board
DRAM_A13: R17.2, U2.N3 (A13), U3.N3 (A13); also elsewhere on the board
DRAM_A14: R20.2, U2.N7 (A14), U3.N7 (A14); also elsewhere on the board
DRAM_BA0: R10.2, U2.J2 (BA0), U3.J2 (BA0); also elsewhere on the board
DRAM_BA1: R12.2, U2.K8 (BA1), U3.K8 (BA1); also elsewhere on the board
DRAM_BA2: R14.2, U2.J3 (BA2), U3.J3 (BA2); also elsewhere on the board
DRAM_CASN: R28.2, U2.G3 (CAS#), U3.G3 (CAS#); also elsewhere on the board
DRAM_CKE: R6.1, R22.2, U2.G9 (CKE), U3.G9 (CKE); also elsewhere on the board
DRAM_CLK_N: R19.2, U2.G7 (CK#), U3.G7 (CK#); also elsewhere on the board
DRAM_CLK_P: R19.1, U2.F7 (CK), U3.F7 (CK); also elsewhere on the board
DRAM_CSN: R7.1, R32.2, U2.H2 (CS#), U3.H2 (CS#); also elsewhere on the board
DRAM_DM0: U2.B7 (DM/TDQS); also elsewhere on the board
DRAM_DM1: U3.B7 (DM/TDQS); also elsewhere on the board
DRAM_DQ0: U2.B3 (DQ0); also elsewhere on the board
DRAM_DQ1: U2.C7 (DQ1); also elsewhere on the board
DRAM_DQ2: U2.D2 (DQ6); also elsewhere on the board
DRAM_DQ3: U2.C8 (DQ3); also elsewhere on the board
DRAM_DQ4: U2.E3 (DQ4); also elsewhere on the board
DRAM_DQ5: U2.E8 (DQ5); also elsewhere on the board
DRAM_DQ6: U2.C2 (DQ2); also elsewhere on the board
DRAM_DQ7: U2.E7 (DQ7); also elsewhere on the board
DRAM_DQ8: U3.B3 (DQ0); also elsewhere on the board
DRAM_DQ9: U3.C7 (DQ1); also elsewhere on the board
DRAM_DQ10: U3.C2 (DQ2); also elsewhere on the board
DRAM_DQ11: U3.C8 (DQ3); also elsewhere on the board
DRAM_DQ12: U3.E3 (DQ4); also elsewhere on the board
DRAM_DQ13: U3.E8 (DQ5); also elsewhere on the board
DRAM_DQ14: U3.D2 (DQ6); also elsewhere on the board
DRAM_DQ15: U3.E7 (DQ7); also elsewhere on the board
DRAM_DQS0_N: U2.D3 (DQS#); also elsewhere on the board
DRAM_DQS0_P: U2.C3 (DQS); also elsewhere on the board
DRAM_DQS1_N: U3.D3 (DQS#); also elsewhere on the board
DRAM_DQS1_P: U3.C3 (DQS); also elsewhere on the board
DRAM_ODT: R30.2, U2.G1 (ODT), U3.G1 (ODT); also elsewhere on the board
DRAM_RASN: R26.2, U2.F3 (RAS#), U3.F3 (RAS#); also elsewhere on the board
DRAM_RSTN: R8.1, U2.N2 (RESET#), U3.N2 (RESET#); also elsewhere on the board
DRAM_WEN: R24.2, U2.H3 (WE#), U3.H3 (WE#); also elsewhere on the board
GND: C1.2, C2.2, C3.2, C4.2, C5.2, C6.2, C7.2, C8.2, C9.2, C10.2, C11.2, C12.2, C13.2, C14.2, C15.2, C16.2, C17.2, C18.2, C19.2, C20.2, C21.2, C22.2, C23.2, C24.2, C25.2, C26.2, C29.2, C30.2, C31.2, C32.2, C33.2, C34.2, C35.2, C36.2, C37.2, C38.2, C39.2, C40.2, C41.2, C42.2, C43.2, C44.2, R3.2, R4.2, R6.2, R7.2, R8.2, U2.A1 (VSS), U2.A8 (VSS), U2.B1 (VSS), U2.B2 (VSSQ), U2.B8 (VSSQ), U2.C9 (VSSQ), U2.D1 (VSSQ), U2.D8 (VSS), U2.D9 (VSSQ), U2.F2 (VSS), U2.F8 (VSS), U2.J1 (VSS), U2.J9 (VSS), U2.L1 (VSS), U2.L9 (VSS), U2.N1 (VSS), U2.N9 (VSS), U3.A1 (VSS), U3.A8 (VSS), U3.B1 (VSS), U3.B2 (VSSQ), U3.B8 (VSSQ), U3.C9 (VSSQ), U3.D1 (VSSQ), U3.D8 (VSS), U3.D9 (VSSQ), U3.F2 (VSS), U3.F8 (VSS), U3.J1 (VSS), U3.J9 (VSS), U3.L1 (VSS), U3.L9 (VSS), U3.N1 (VSS), U3.N9 (VSS); also elsewhere on the board
unnamed: R3.1, U2.H8 (ZQ)
unnamed: R4.1, U3.H8 (ZQ)
VREF_DDR: C25.1, C26.1, U2.E1 (VREFDQ), U2.J8 (VREFCA), U3.E1 (VREFDQ), U3.J8 (VREFCA); also elsewhere on the board

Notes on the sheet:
need termination for data mask ?
DDR3L-2
DDR3L-1
VTT bypass cap. and termination

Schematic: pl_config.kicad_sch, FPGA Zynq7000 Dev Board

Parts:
C45, C46: 100n; C_0402_1005Metric
D1: RED; LED_0603_1608Metric
D2: GREEN; LED_0603_1608Metric
D3: BLUE; LED_0603_1608Metric
J3: Header 2.54mm; PinHeader_1x06_P2.54mm_Vertical
R34, R36, R37: 10k; R_0402_1005Metric
R35, R38, R40, R43: 4k7; R_0402_1005Metric
R39, R41: 1k; R_0402_1005Metric
R42: 330R; R_0402_1005Metric
SW1, SW2: SW_Push; SW_Push_1P1T_NO_Vertical_Wuerth_434133025816
U1: XC7Z010-1CLG400C; CLG400_XIL-L

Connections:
+3V3: R34.1, R35.1, R36.1, R37.1, R38.1, R39.1, R40.2, R42.1, U1.M6 (CFGBVS_0); also elsewhere on the board
/PL Configuration/FPGA_PL_DONE: D3.2 (A), R42.2, U1.R11 (DONE_0)
/PL Configuration/FPGA_PL_INIT_B: D1.1 (K), D2.2 (A), R39.2, U1.R10 (INIT_B_0)
/PL Configuration/FPGA_PL_PROGRAM_B: C45.2, R38.2, SW1.2, U1.L6 (PROGRAM_B_0)
FPGA_PS_CLK_40MHz: U1.E7 (PS_CLK_500); also elsewhere on the board
FPGA_PS_SRST_B: C46.2, J3.1, R35.2, SW2.2, U1.B10 (PS_SRST_B_501); also elsewhere on the board
FPGA_TCK: J3.2, R36.2, U1.F9 (TCK_0); also elsewhere on the board
FPGA_TDI: J3.4, U1.G6 (TDI_0); also elsewhere on the board
FPGA_TDO: J3.3, U1.F6 (TDO_0); also elsewhere on the board
FPGA_TMS: J3.5, R37.2, U1.J6 (TMS_0); also elsewhere on the board
GND: C45.1, C46.1, J3.6, R41.2, R43.2, SW1.1, SW2.1; also elsewhere on the board
unnamed: D1.2 (A), R40.1
unnamed: D2.1 (K), R41.1
unnamed: D3.1 (K), R43.1
PMIC_MCU_NRST: R34.2, U1.C7 (PS_POR_B_500); also elsewhere on the board

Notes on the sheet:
PL Configuration
Configuration Block and JTAG conn.
OK PS_POR_B input is required to be asserted to GND during the power-on sequence OK The PS system reset (PS_SRST_B) is an active-Low signal that is mostly used for debugging proposes. OK PS_SRST_B must be High to begin the boot process OK 30MHz < PS_CLK < 60MHz OK TMS and TCK have 10k pull up OK PR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
DONE = 1: Done configuration INIT_B = 0: Open-drain, initialization of configuration memory PROGRAM_B = 0: Asynchronous reset of configuration logic CFGBVS = VCCO_0: MUST DO. Select the voltage level of 3.3V for configuration bank

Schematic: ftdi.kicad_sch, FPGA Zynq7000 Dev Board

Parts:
C157, C168: 4u7; C_0402_1005Metric
C158, C159, C160, C161, C162, C163, C164, C165, C166, C167, C169: 100n; C_0402_1005Metric
C170, C171: 10p; C_0402_1005Metric
FB1: 600R; L_0603_1608Metric
J11: USB_C_Receptacle_USB2.0_16P; USB_C_Receptacle_GCT_USB4105-xx-A_16P_TopMnt_Horizontal
R87, R88: 5k1; R_0402_1005Metric
R89, R95: 2k; R_0402_1005Metric
R90, R92, R93, R94: 10k; R_0402_1005Metric
R91: 1k; R_0402_1005Metric
U9: FT4232H; LQFP-64_10x10mm_P0.5mm
U10: AT93C46-10SU-2.7-T; SOIC8_4P9X3P9MC_MCH
Y2: 12MHz; Crystal_SMD_3225-4Pin_3.2x2.5mm

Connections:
+1V8_FTDI: C165.1, C166.1, C167.1, C168.1, U9.12 (VCORE), U9.37 (VCORE), U9.49 (VREGOUT), U9.64 (VCORE)
+3V3: C160.1, C161.1, C162.1, C163.1, C164.1, C169.1, FB1.1, R91.1, R92.1, R93.1, R94.1, U9.20 (VCCIO), U9.21 (ADBUS4), U9.31 (VCCIO), U9.42 (VCCIO), U9.50 (VREGIN), U9.56 (VCCIO), U10.2 (VCC), U10.8 (ORG); also elsewhere on the board
+3V3_PLL: C157.1, C158.1, C159.1, FB1.2, U9.4 (VPHY), U9.9 (VPLL)
/FTDI/FTDI_EEPROM_CS: R92.2, U9.63 (EECS), U10.3 (CS)
/FTDI/FTDI_EEPROM_DATA: R95.2, U9.61 (EEDATA), U10.5 (DI)
/FTDI/FTDI_EEPROM_SCK: R93.2, U9.62 (EECLK), U10.4 (SK)
/FTDI/USB_JTAG_D+: J11.A6 (D+), J11.B6 (D+), U9.8 (DP)
/FTDI/USB_JTAG_D-: J11.A7 (D-), J11.B7 (D-), U9.7 (DM)
FPGA_PS_SRST_B: U9.23 (ADBUS6); also elsewhere on the board
FPGA_TCK: U9.16 (ADBUS0); also elsewhere on the board
FPGA_TDI: U9.17 (ADBUS1); also elsewhere on the board
FPGA_TDO: U9.18 (ADBUS2); also elsewhere on the board
FPGA_TMS: U9.19 (ADBUS3); also elsewhere on the board
GND: C157.2, C158.2, C159.2, C160.2, C161.2, C162.2, C163.2, C164.2, C165.2, C166.2, C167.2, C168.2, C169.2, C170.2, C171.2, J11.A1 (GND), J11.A12 (GND), J11.B1 (GND), J11.B12 (GND), R87.2, R88.2, R89.2, U9.1 (GND), U9.5 (GND), U9.10 (AGND), U9.11 (GND), U9.13 (TEST), U9.15 (GND), U9.25 (GND), U9.35 (GND), U9.47 (GND), U9.51 (GND), U10.7 (GND), Y2.2, Y2.4; also elsewhere on the board
unnamed: J11.A5 (CC1), R87.1
unnamed: J11.B5 (CC2), R88.1
unnamed: R89.1, R90.2
unnamed: C170.1, U9.2 (OSCI), Y2.3
unnamed: C171.1, U9.3 (OSCO), Y2.1
unnamed: R90.1, U9.6 (REF)
unnamed: R91.2, U9.14 (~RESET)
unnamed: R94.2, R95.1, U10.6 (DO)
UART1_RX: U9.26 (BDBUS0); also elsewhere on the board
UART1_TX: U9.27 (BDBUS1); also elsewhere on the board
UART2_RX: U9.38 (CDBUS0); also elsewhere on the board
UART2_TX: U9.39 (CDBUS1); also elsewhere on the board
UART3_RX: U9.48 (DDBUS0); also elsewhere on the board
UART3_TX: U9.52 (DDBUS1); also elsewhere on the board

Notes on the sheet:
FTDI USB-JTAG

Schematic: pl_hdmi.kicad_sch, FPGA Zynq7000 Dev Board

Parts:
J12: HDMI_A_1.4; HDMI_A_Molex_208658-1001_Horizontal
Q1, Q2, Q3: 2N7002; SOT-23
R96, R97, R98, R99, R100: 4k7; R_0402_1005Metric

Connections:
+3V3: Q1.1 (G), Q2.1 (G), R96.1, R97.1, R100.1; also elsewhere on the board
/HDMI/HDMI_HPD: J12.19 (HPD/HEAC-), Q3.1 (G)
/HDMI/HDMI_I2C_SCL_50: J12.15 (SCL), Q1.3 (D), R99.2
/HDMI/HDMI_I2C_SDA_50: J12.16 (SDA), Q2.3 (D), R98.2
GND: J12.2 (D2S), J12.5 (D1S), J12.8 (D0S), J12.11 (CKS), J12.17 (GND), J12.SH, Q3.2 (S); also elsewhere on the board
HDMI_CEC: J12.13 (CEC); also elsewhere on the board
HDMI_CLK_N: J12.12 (CK-); also elsewhere on the board
HDMI_CLK_P: J12.10 (CK+); also elsewhere on the board
HDMI_DAT0_N: J12.9 (D0-); also elsewhere on the board
HDMI_DAT0_P: J12.7 (D0+); also elsewhere on the board
HDMI_DAT1_N: J12.6 (D1-); also elsewhere on the board
HDMI_DAT1_P: J12.4 (D1+); also elsewhere on the board
HDMI_DAT2_N: J12.3 (D2-); also elsewhere on the board
HDMI_DAT2_P: J12.1 (D2+); also elsewhere on the board
HDMI_HP_DET: Q3.3 (D), R100.2; also elsewhere on the board
HDMI_I2C_SCL: Q1.2 (S), R96.2; also elsewhere on the board
HDMI_I2C_SDA: Q2.2 (S), R97.2; also elsewhere on the board
VBUS1: J12.18 (+5V), R98.1, R99.1; also elsewhere on the board

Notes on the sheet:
HDMI

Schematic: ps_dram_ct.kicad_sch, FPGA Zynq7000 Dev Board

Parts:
C27, C28: 100n; C_0402_1005Metric
R2, R5: 120R; R_0402_1005Metric
U1: XC7Z010-1CLG400C; CLG400_XIL-L

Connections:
+1V35: R2.1; also elsewhere on the board
DRAM_A0: U1.N2 (PS_DDR_A0_502); also elsewhere on the board
DRAM_A1: U1.K2 (PS_DDR_A1_502); also elsewhere on the board
DRAM_A2: U1.M3 (PS_DDR_A2_502); also elsewhere on the board
DRAM_A3: U1.K3 (PS_DDR_A3_502); also elsewhere on the board
DRAM_A4: U1.M4 (PS_DDR_A4_502); also elsewhere on the board
DRAM_A5: U1.L1 (PS_DDR_A5_502); also elsewhere on the board
DRAM_A6: U1.L4 (PS_DDR_A6_502); also elsewhere on the board
DRAM_A7: U1.K4 (PS_DDR_A7_502); also elsewhere on the board
DRAM_A8: U1.K1 (PS_DDR_A8_502); also elsewhere on the board
DRAM_A9: U1.J4 (PS_DDR_A9_502); also elsewhere on the board
DRAM_A10: U1.F5 (PS_DDR_A10_502); also elsewhere on the board
DRAM_A11: U1.G4 (PS_DDR_A11_502); also elsewhere on the board
DRAM_A12: U1.E4 (PS_DDR_A12_502); also elsewhere on the board
DRAM_A13: U1.D4 (PS_DDR_A13_502); also elsewhere on the board
DRAM_A14: U1.F4 (PS_DDR_A14_502); also elsewhere on the board
DRAM_BA0: U1.L5 (PS_DDR_BA0_502); also elsewhere on the board
DRAM_BA1: U1.R4 (PS_DDR_BA1_502); also elsewhere on the board
DRAM_BA2: U1.J5 (PS_DDR_BA2_502); also elsewhere on the board
DRAM_CASN: U1.P5 (PS_DDR_CAS_B_502); also elsewhere on the board
DRAM_CKE: U1.N3 (PS_DDR_CKE_502); also elsewhere on the board
DRAM_CLK_N: U1.M2 (PS_DDR_CKN_502); also elsewhere on the board
DRAM_CLK_P: U1.L2 (PS_DDR_CKP_502); also elsewhere on the board
DRAM_CSN: U1.N1 (PS_DDR_CS_B_502); also elsewhere on the board
DRAM_DM0: U1.A1 (PS_DDR_DM0_502); also elsewhere on the board
DRAM_DM1: U1.F1 (PS_DDR_DM1_502); also elsewhere on the board
DRAM_DQ0: U1.B3 (PS_DDR_DQ1_502); also elsewhere on the board
DRAM_DQ1: U1.D1 (PS_DDR_DQ5_502); also elsewhere on the board
DRAM_DQ2: U1.A4 (PS_DDR_DQ3_502); also elsewhere on the board
DRAM_DQ3: U1.D3 (PS_DDR_DQ4_502); also elsewhere on the board
DRAM_DQ4: U1.A2 (PS_DDR_DQ2_502); also elsewhere on the board
DRAM_DQ5: U1.E1 (PS_DDR_DQ7_502); also elsewhere on the board
DRAM_DQ6: U1.C3 (PS_DDR_DQ0_502); also elsewhere on the board
DRAM_DQ7: U1.C1 (PS_DDR_DQ6_502); also elsewhere on the board
DRAM_DQ8: U1.E3 (PS_DDR_DQ9_502); also elsewhere on the board
DRAM_DQ9: U1.H3 (PS_DDR_DQ11_502); also elsewhere on the board
DRAM_DQ10: U1.H2 (PS_DDR_DQ13_502); also elsewhere on the board
DRAM_DQ11: U1.J3 (PS_DDR_DQ12_502); also elsewhere on the board
DRAM_DQ12: U1.E2 (PS_DDR_DQ8_502); also elsewhere on the board
DRAM_DQ13: U1.J1 (PS_DDR_DQ15_502); also elsewhere on the board
DRAM_DQ14: U1.G3 (PS_DDR_DQ10_502); also elsewhere on the board
DRAM_DQ15: U1.H1 (PS_DDR_DQ14_502); also elsewhere on the board
DRAM_DQS0_N: U1.B2 (PS_DDR_DQS_N0_502); also elsewhere on the board
DRAM_DQS0_P: U1.C2 (PS_DDR_DQS_P0_502); also elsewhere on the board
DRAM_DQS1_N: U1.F2 (PS_DDR_DQS_N1_502); also elsewhere on the board
DRAM_DQS1_P: U1.G2 (PS_DDR_DQS_P1_502); also elsewhere on the board
DRAM_ODT: U1.N5 (PS_DDR_ODT_502); also elsewhere on the board
DRAM_RASN: U1.P4 (PS_DDR_RAS_B_502); also elsewhere on the board
DRAM_RSTN: U1.B4 (PS_DDR_DRST_B_502); also elsewhere on the board
DRAM_WEN: U1.M5 (PS_DDR_WE_B_502); also elsewhere on the board
GND: C27.2, C28.2, R5.2; also elsewhere on the board
unnamed: R2.2, U1.G5 (PS_DDR_VRN_502)
unnamed: R5.1, U1.H5 (PS_DDR_VRP_502)
VREF_DDR: C27.1, C28.1, U1.H6 (PS_DDR_VREF0_502), U1.P6 (PS_DDR_VREF1_502); also elsewhere on the board

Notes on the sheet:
DRAM Controller

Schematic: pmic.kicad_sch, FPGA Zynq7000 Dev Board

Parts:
C58, C72, C75, C80: 100n; C_0402_1005Metric
C59, C60, C61, C62, C63, C64, C65: 10u; C_0402_1005Metric
C66, C67, C68, C69, C70, C71, C73, C74, C77, C78: 22u; C_0603_1608Metric
C76, C81, C82, C83, C84, C175: 1u; C_0402_1005Metric
C79, C174: 4u7; C_0402_1005Metric
IC1: MMPF0100NPAEP; QFN-56-1EP_8x8mm_P0.5mm_EP4.3x4.3mm; Manufacturer_Part_Number MMPF0100NPAEP; Mouser Part Number 841-MMPF0100NPAEP
J5: Header 2.54mm; PinHeader_1x05_P2.54mm_Vertical
L1, L2, L3, L4, L5: 1u; L_Chilisin_BMRA00040420
R56, R57: 4k7; R_0402_1005Metric
R58: 100k; R_0402_1005Metric
R59: DNP; R_0402_1005Metric
R60: DNP; R_0402_1005Metric; not fitted
SW3: SW_Push; SW_Push_1P1T_NO_Vertical_Wuerth_434133025816

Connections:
+0V675: C77.1, C78.1, IC1.19 (SW4FB), L5.2; also elsewhere on the board
+1V0: C66.1, C67.1, IC1.13 (SW1CFB), L1.2; also elsewhere on the board
+1V8: C68.1, C69.1, IC1.25 (SW2FB), L2.2; also elsewhere on the board
+1V8A: C174.1, IC1.28 (VGEN4); also elsewhere on the board
+1V35: C70.1, C71.1, C72.1, IC1.30 (VINREFDDR), IC1.38 (SW3AFB), L3.2; also elsewhere on the board
+3V3: C73.1, C74.1, C175.1, IC1.17 (VIN1), IC1.27 (VIN2), IC1.33 (SW3BFB), IC1.40 (VIN3), L4.2, R60.2; also elsewhere on the board
/PMIC/VSNVS: C81.1, IC1.43 (VSNVS), R58.1
GND: C58.1, C59.2, C60.2, C61.2, C62.2, C63.2, C64.2, C65.2, C66.2, C67.2, C68.2, C69.2, C70.2, C71.2, C73.2, C74.2, C75.2, C76.2, C77.2, C78.2, C79.2, C80.2, C81.2, C82.2, C83.2, C84.2, C174.2, C175.2, IC1.4 (STANDBY), IC1.5 (ICTEST), IC1.14 (SW1VSSSNS), IC1.15 (GNDREF), IC1.32 (SW3VSSSNS), IC1.48 (GNDREF), IC1.57 (EPAD), J5.5, R59.2, SW3.1; also elsewhere on the board
unnamed: C80.1, IC1.42 (LICELL)
unnamed: IC1.8 (SW1ALX), IC1.9 (SW1BLX), IC1.11 (SW1CLX), L1.1
unnamed: IC1.22 (SW2LX), L2.1
unnamed: IC1.36 (SW3ALX), L3.1
unnamed: IC1.35 (SW3BLX), L4.1
unnamed: IC1.21 (SW4LX), L5.1
unnamed: C84.1, IC1.49 (VCORE)
unnamed: C82.1, IC1.51 (VCOREDIG)
unnamed: C83.1, IC1.52 (VCOREREF)
unnamed: C72.2, C75.1, IC1.29 (VHALF)
PMIC_I2C_SCL: IC1.54 (SCL), J5.3, R56.2; also elsewhere on the board
PMIC_I2C_SDA: IC1.53 (SDA), J5.4, R57.2; also elsewhere on the board
PMIC_MCU_NRST: IC1.3 (RESETBMCU); also elsewhere on the board
PMIC_PWRON: C58.2, IC1.56 (PWRON), R58.2, SW3.2; also elsewhere on the board
PMIC_VDDIO: IC1.55 (VDDIO), J5.2, R56.1, R57.1, R60.1
PMIC_VDDOTP: IC1.47 (VDDOTP), J5.1, R59.1
VREF_DDR: C76.1, IC1.31 (VREFDDR); also elsewhere on the board
VSYS: C59.1, C60.1, C61.1, C62.1, C63.1, C64.1, C65.1, C79.1, IC1.7 (SW1AIN), IC1.10 (SW1BIN), IC1.12 (SW1CIN), IC1.20 (SW4IN), IC1.23 (SW2IN), IC1.24 (SW2IN), IC1.34 (SW3BIN), IC1.37 (SW3AIN), IC1.45 (SWBSTIN), IC1.50 (VIN); also elsewhere on the board

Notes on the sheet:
populate when done programing
PMIC programming header
OK INTB, SDWNB: Leave floating OK RESETBMCU. Pull up to 3.3V (< Vin) with 100k. OK STANDBY, ICTEST = GND OK SW1ABC single phase mode OK SW1FB floating OK SW1CFB real feedback OK VIN123 connected to V < 3.4V OK LICELL bypass with 0.1u OK VSNVS bypass with 0.47u OK SWBSTFB floating OK SWBSTIN to VIN 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
PMIC
SW1ABC: 1.00V, 4.50A, to Core SW2: 1.80V, 2.50A, to AUX SW3A: 1.35V, 1.25A, to DRAM SW3B: 3.30V, 1.25A, to IO SW4: .675V, 1.00A, to VTT VREFDDR: .675V, 0.01A, to DRAM reference

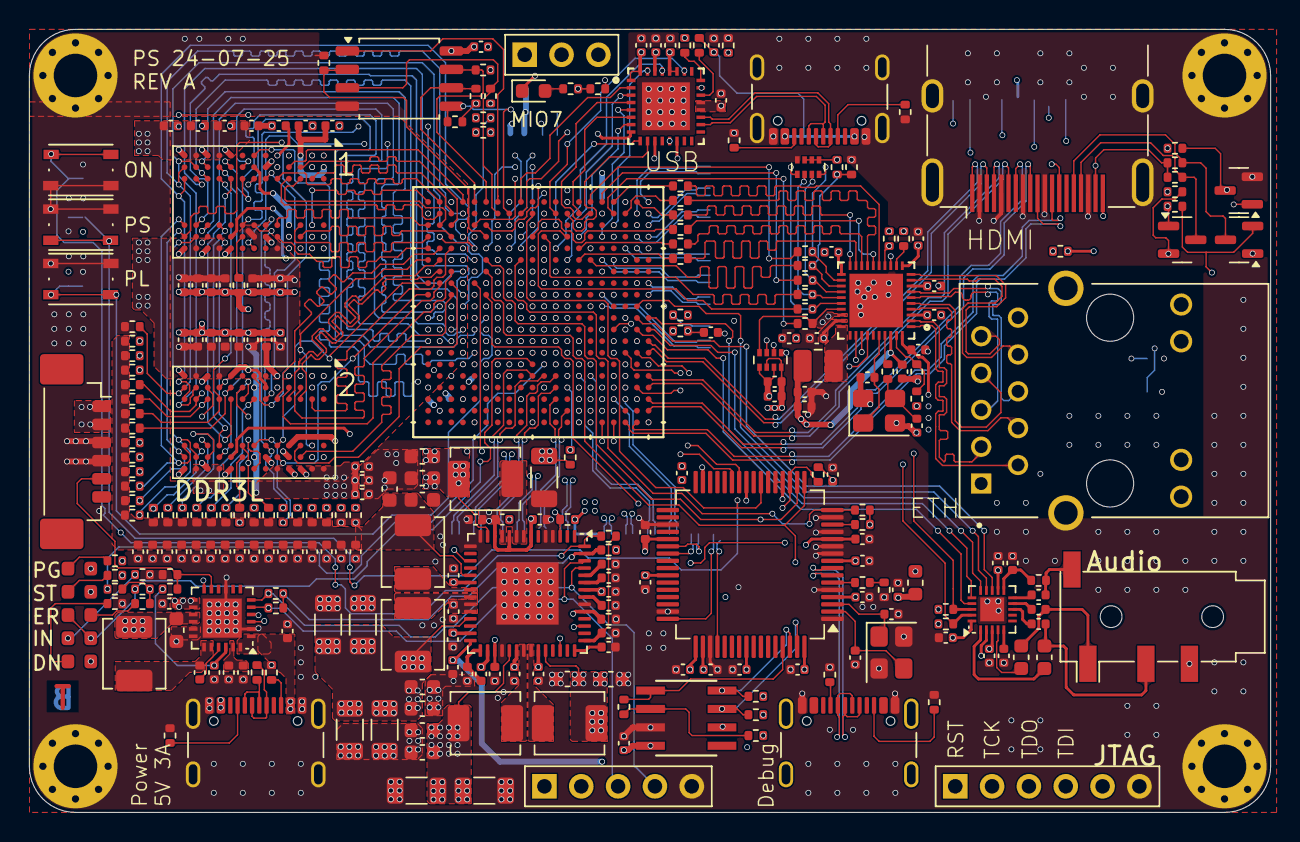
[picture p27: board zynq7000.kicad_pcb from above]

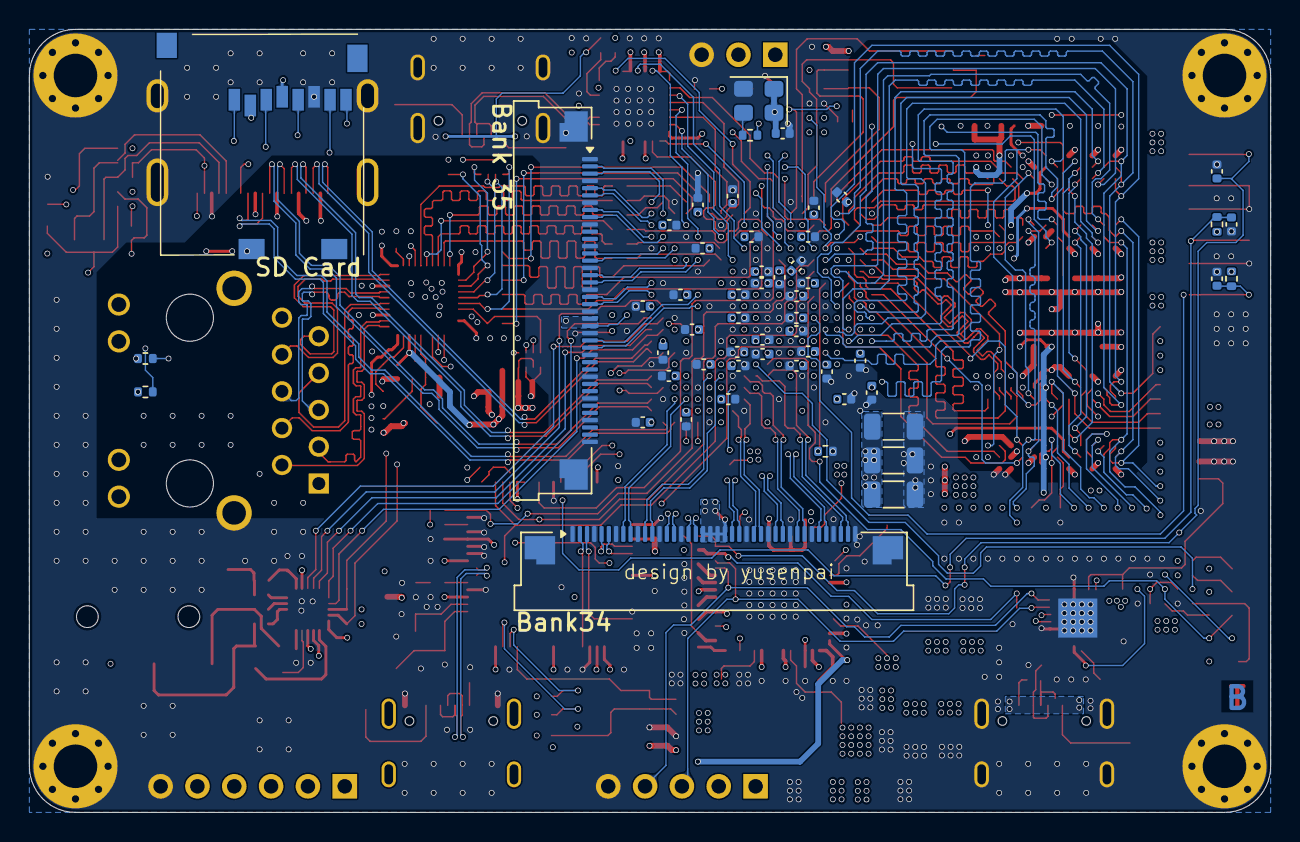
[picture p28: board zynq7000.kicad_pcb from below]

Board: 6 copper layers, 85.6 x 54.0 mm, 336 parts (54 on the bottom side), 280 nets.
